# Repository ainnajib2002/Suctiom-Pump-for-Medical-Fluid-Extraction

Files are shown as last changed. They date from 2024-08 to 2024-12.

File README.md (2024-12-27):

## Suction-Pump-for-Medical-Fluid-Extraction








# Suction Pump for Medical Fluid Extraction

## Deskripsi Proyek
Suction Pump adalah alat medis untuk menghisap berbagai jenis cairan tubuh seperti darah, lendir, dan nanah selama prosedur medis. Proyek ini dirancang untuk menghasilkan suction pump berbasis mikrokontroler Arduino Mega dengan fitur IoT, keypad, dan LCD untuk pemantauan dan kontrol yang lebih baik.

---

## Fitur Utama
- **IoT Integration**: Pemantauan dan kontrol jarak jauh melalui cloud.
- **User Interface**: Keypad 4x4 dan LCD 20x4 untuk pengoperasian mudah.
- **Safety Design**: Bahan stainless steel untuk ketahanan dan kebersihan.

---

## Alat dan Bahan
| Komponen | Deskripsi |
|---|---|
| **Mikrokontroler**  | Arduino Mega |
| **Sensor** | MPX 5700 untuk tekanan |
| **Komponen Elektrik**| LCD 20x4, Keypad Matrix 4x4, Driver Motor L298N, Potentiometer |
| **Komponen Mekanikal**| Bahan stainless steel untuk casing dan komponen mekanis lainnya |

---

## Desain 3D
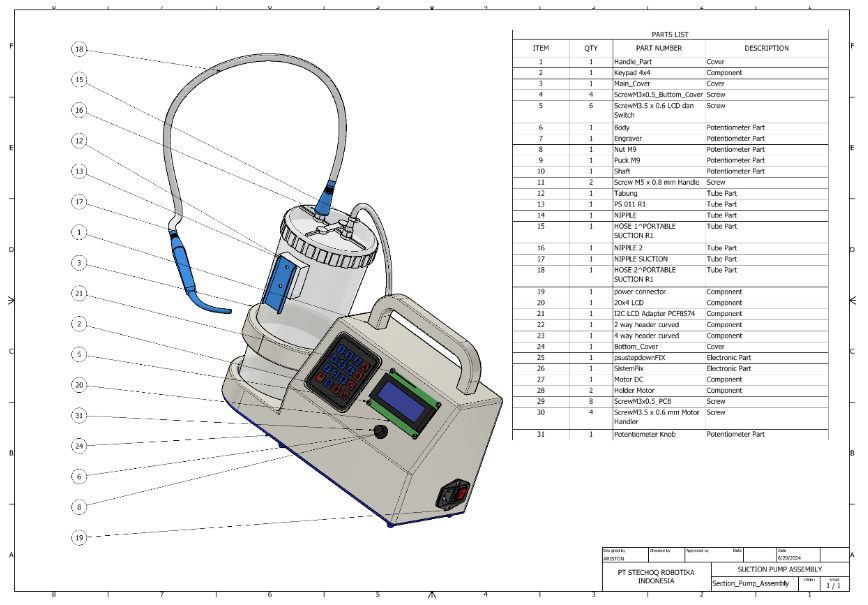
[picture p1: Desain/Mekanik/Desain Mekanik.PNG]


## Skema Rangkaian


---

## Panduan Instalasi dan Penggunaan
1. **Persiapan Hardware**: 
   - Rakit semua komponen sesuai skema.
   - Pastikan koneksi ke ESP32 dan sistem mekanik sudah sesuai.
2. **Instalasi Software**:
   - Gunakan Arduino IDE untuk mengunggah kode ke mikrokontroler.
3. **Konfigurasi IoT**:
   - Masukkan detail WiFi melalui keypad untuk koneksi cloud.
4. **Pengoperasian**:
   - Gunakan keypad untuk mengatur kecepatan dan parameter operasi.
   - Pantau informasi pada LCD 20x4.

---

## Sumber
- [Arduino IDE](https://www.arduino.cc/en/software)
- [Komponen ESP32](https://www.espressif.com/en/products/socs/esp32)

---

Jika desain ini sudah sesuai, saya dapat menambahkan detail lainnya. Silakan beri tahu!

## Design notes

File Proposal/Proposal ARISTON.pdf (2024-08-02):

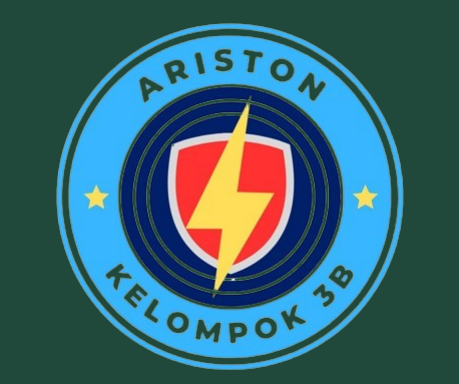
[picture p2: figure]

# ARISTON TEAM

## PT. STECHOQ ROBOTIKA INDONESIA

Jl. Bunga J5, Kentungan, Condongcatur, Depok,

### Sleman, D.I. Yogyakarta 55281

ASSOCIATED WITH :

# Project Proposal

# Suction Pump for Medical Fluid Extraction

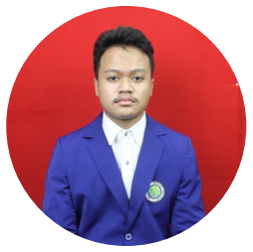
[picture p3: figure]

Sholich Ibnu Damar

3D Design
Universitas Negeri Malang

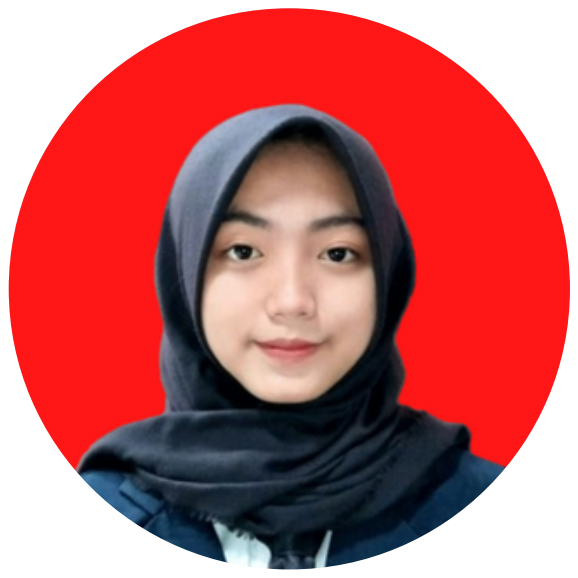
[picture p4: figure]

Tri Rejeki Andani

3D Design
Universitas Negeri Surabaya

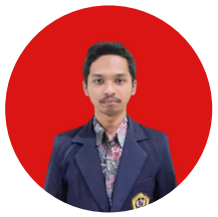
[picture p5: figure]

Sri Aji Eka Mahendra

Electronics Engineer
Universitas Merdeka Malang

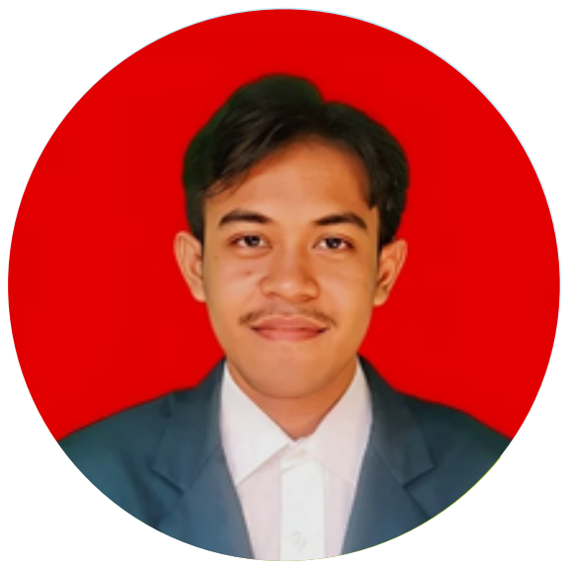
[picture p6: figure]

Ainun Najib Khasbunallah

Project Manager and Electronics Engineer Universitas Diponegoro Semarang

# OUR TEAM

### SUCTION PUMP FOR MEDICAL FLUID EXTRACTION

ARISTON | PAGE 1

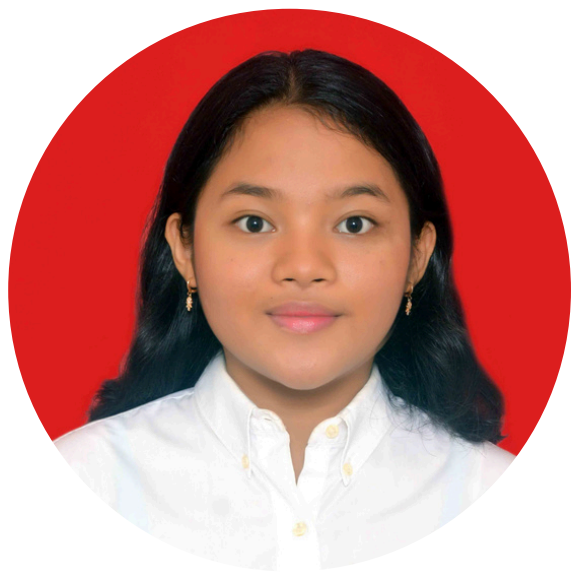
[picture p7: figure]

Aurelia Alika Putri Widiyanta

Administratif and Support Engineer Politeknik Negeri Semarang

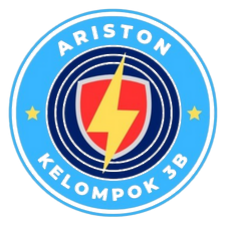
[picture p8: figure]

### ARISTON

Jl. Bunga J5, Kentungan, Condongcatur, Kab. Depok, Kab. Sleman, Daerah Istimewa Yogyakarta

### HALAMAN PENGESAHAN

### 1. Nama Proyek : Project Proposal Suction Pump for Medical Fluid Extraction 2. Bidang Riset : Hardware Engineering 3. Nama Tim : ARISTON 4. Anggota Tim : - Ainun Najib Khasbunallah - Aurelia Alika Putri Widiyanta - Sholich Ibnu Damar - Sri Aji Eka Mahendra - Tri Rejeki Andani

### Sleman, 24 Mei 2024

Menyetujui,

Koordinator Lapangan | Project Manager
(Nama) | Ainun Najib Khasbunallah

Mengetahui,

Direktur Utama PT. Stechoq | Person In charge

### Robotika Indonesia

Malik Khidir, S.Si | Febri Hari Natoro, S.Psi

# Daftar Isi

01

## BAB 1 – PENDAHULUAN

## Latar Belakang

## Rumusan Masalah Tujuan dan Sasaran

## Scope Of Work

## ANGGOTA TIM

## HALAMAN PENGESAHAN

## DAFTAR ISI

## BAB 2 – DETAIL PROYEK

## Deskripsi Produk

## Sistem Kerja Alat

## Spesifikasi Alat

## Skema Elektronik

## BAB 3 - METODE DAN TAHAPAN

## Timeline

## Work Breakdown Structure Rencana Anggaran Biaya

## BAB 4 – PENUTUP

## Penutup

## LAMPIRAN

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
Suction pump adalah perangkat medis yang dirancang khusus untuk menghisap cairan tubuh. Suction pump medis dapat digunakan dalam berbagai penerapan pada bidang medis, termasuk di ruang operasi, unit perawatan intensif, ruang gawat darurat, atau klinik medis. Dalam industri perawatan kesehatan, mesin suction pump telah menjadi bagian penting dalam proses penghisapan cairan tubuh pasien selama prosedur medis. Dalam produk ini penggunaannya dilengkapi dengan kontrol yang memungkinkan pengaturan tingkat hisap yang diperlukan sesuai dengan kebutuhan spesifik prosedur atau kondisi pasien untuk membantu meningkatkan efisiensi, keamanan, dan kualitas perawatan pasien.

Berdasarkan hal ini, kami dari peserta studi independen PT Stechoq Robotika Indonesia berusaha untuk memberikan kontribusi dalam menyelesaikan permasalahan yang terjadi dan meningkatkan efisiensi dalam industri perawatan kesehatan. Pada program studi independen MSIB batch VI, dirancang sebuah inovasi “Suction Pump for Medical Fluid Extraction” yang merupakan produk inovatif dalam industri perawatan kesehatan dengan mesin suction pump. Penggunaan inovasi ini diharapkan dapat mempermudah operator perawatan kesehatan dalam memantau kinerja mesin suction pump Dengan ini diharapkan produk inovasi Suction Pump for Medical Fluid Extraction memberikan solusi yang canggih dan efisien dalam pemantauan dan pemeliharaan mesin suction pump, yang dapat meningkatkan efisiensi, kebersihan, dan keamanan dalam industri perawatan kesehatan.

## LATAR BELAKANG

# BAB 1 PENDAHULUAN

Berdasarkan latar belakang tersebut, didapatkan rumusan masalah, yaitu :
Bagaimana merancang suction pump yang efisien untuk digunakan dalam berbagai prosedur medis?

1.

2.Bagaimana menghubungkan teknologi IoT dalam suction pump?

## RUMUSAN MASALAH

Tujuan dari produk ini yaitu :
Mengembangkan desain rancangan suction pump yang mampu bekerja untuk berbagai kebutuhan medis, termasuk pembedahan dan perawatan pasien dengan gangguan cairan.

1.

Menghubungkan suction pump dengan teknologi Internet of Things (IoT) untuk meningkatkan kinerja, pemantauan, dan manajemen perangkat medis secara real-time.

2.

## TUJUAN DAN SASARAN

Ruang lingkup dari pengerjaan ini adalah :
1.Pembuatan desain mekanik dan elektrik 2.Pembuatan program
3.Peragaan simulasi alat

## SCOPE OF WORK

Suction Pump for Medical Fluid Extraction adalah perangkat medis yang dirancang khusus untuk mengeluarkan cairan tubuh seperti darah, lendir, dan cairan lainnya dari tubuh pasien atau area operatif secara cepat dan efisien. Alat ini sangat penting dalam berbagai prosedur medis, termasuk pembedahan, perawatan pasien dengan gangguan cairan, dan situasi darurat medis. Suction pump ini menawarkan solusi andal untuk meningkatkan kualitas pelayanan kesehatan. Selain itu, suction pump ini dilengkapi dengan layanan IoT (Internet of Things) yang memungkinkan pemantauan kinerja alat secara real-time yang optimal dan mengurangi downtime.

## DESKRIPSI PRODUK

# BAB 2 DETAIL PROYEK

Sistem ini dimulai dengan pemeriksaan status alat. Jika status alat baik, kemudian menkoneksikan Wi_Fi untuk terhubung dengan API Cloud. Pengguna dapat memilih mode kontrol mesin suction pump via keypad atau via IoT dengan menu slider. Setelah memasukkan RPM motor yang diinginkan dan menekan tombol untuk memulai pengisian. Motor kemudian memompa cairan ke dalam tabung sesuai RPM yang ditentukan.
Hasil pengisian ditampilkan pada layar LCD dan dikirim ke cloud melalui API. Data hasil pengisian dikirim ke database dan dapat dipantau melalui platform cloud. Sistem memastikan pengisian cairan otomatis dengan pemantauan real-time melalui LCD dan cloud, serta penyimpanan data yang efisien. Proses diakhiri setelah semua langkah selesai.

## SISTEM KERJA ALAT

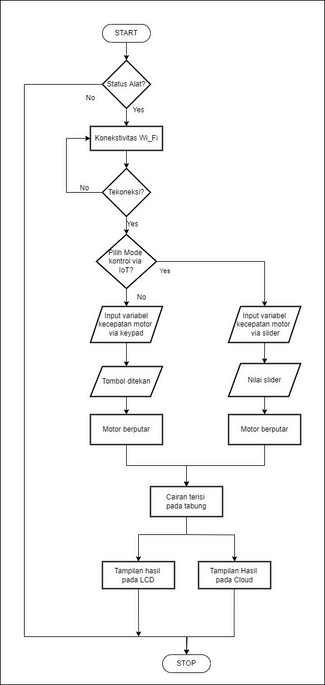
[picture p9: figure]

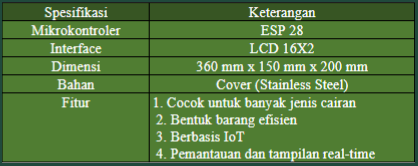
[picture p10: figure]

## LCD Keypad 16x2

## ESP32

## SPESIFIKASI ALAT

# BAB 2 DETAIL PROYEK

## Motor DC

## Tombol Keypad 4x4

## Potensiometer

## Power Supply 12V

## Stepdown 5V

## Push Button On/ Off

## SKEMA ELEKTRONIK

## TIMELINE

# BAB 3 METODE DAN TAHAPAN

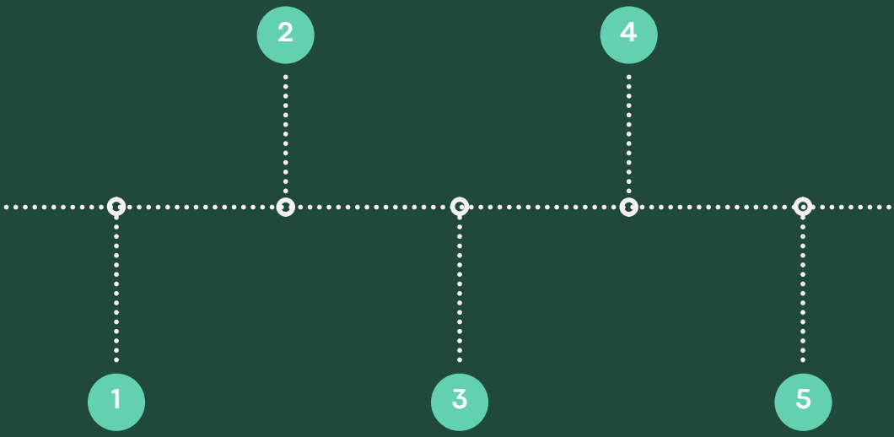
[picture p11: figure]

### Persiapan Pelaksanaan

### Pelaporan

### Perancangan

### Pengujian

Persiapan (1 Maret - 16 Maret)

Analisis tujuan dari project ARISTON, Pengumpulan data dan informasi produk, Analisis cara kerja dan komponen yang digunakan

Perancangan (17 Maret - 6 April)

Perancangan design 3d suction pump, Perancangan bahasa pemrograman C++, Perancangan design elektronika suction pump

Pelaksanaan (7 April - 30 April)

Membuat part-part design 3D suction pump, Membuat bahasa program arduino C++, pembuatan 3D animasi suction pump, Assembly design schematic rangkaian elektronika suction pump, Assembly design layout rangkaian elektronika suction pump, Assembly design 3D suction pump, Integrasi sistem suction pump dengan bahasa program

Pengujian (1 Mei - 25 Mei)

Pengujian fungsi dan kinerja sistem suction pump, Finishing dan evaluasi suction pump

Pelaporan (19 Mei- 10 Juni)

Pembuatan dan penyusunan laporan akhir, Presentasi project

## WORK BREAKDOWN STRUCTURE

# BAB 3 METODE DAN TAHAPAN

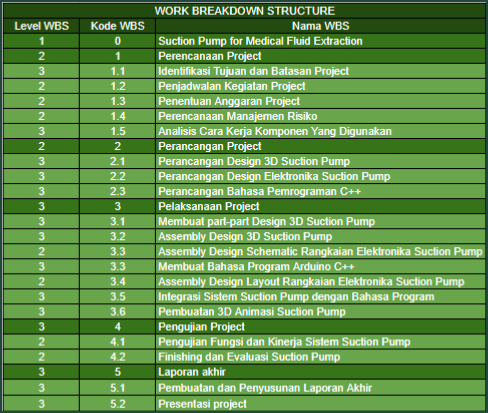
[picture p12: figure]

No | Nama | Harga
1. | Biaya elektrikal | Rp. 637.528
2. | Biaya mekanikal | Rp. 1.500.000
| Total | Rp. 2.137.528

## RENCANA ANGGARAN BIAYA

# BAB 3 METODE DAN TAHAPAN

## PENUTUP

# BAB 4 PENUTUP

Demikian proposal suction pump for medical fluid extraction dibuat dengan harapan alat ini tidak hanya meningkatkan efisiensi operasional dan kontrol yang presisi, tetapi juga memastikan keamanan dan kenyamanan bagi pengguna. Dengan kemampuan pemantauan real-time, pengendalian jarak jauh, analisis data yang mendalam, dan integrasi dengan sistem medis lainnya, perangkat ini siap mendukung para profesional medis dalam memberikan perawatan yang lebih baik dan responsif. Inovasi ini memperkuat komitmen terhadap kemajuan teknologi medis yang berpusat pada keselamatan dan kesejahteraan pasien, menjadikannya aset berharga dalam lingkungan medis modern.

# LAMPIRAN

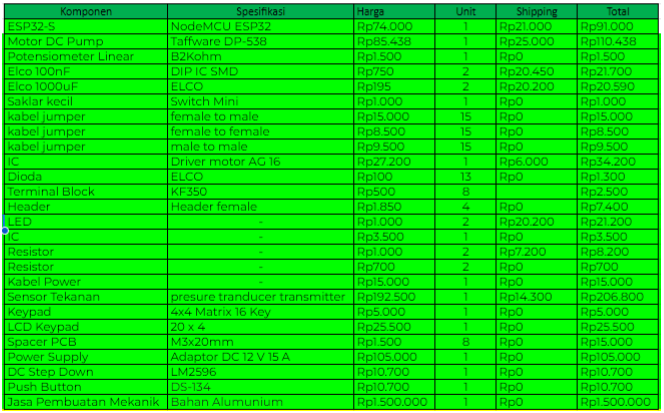
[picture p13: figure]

For inquiries,
contact ARISTON.

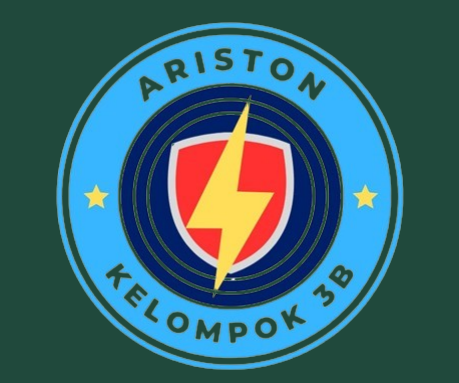
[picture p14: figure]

+62 857-1358-7044 (Ainun Najib) aristonhwstechoq@gmail.com

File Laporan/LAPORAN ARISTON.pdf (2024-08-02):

LAPORAN AKHIR
MAGANG DAN STUDI INDEPENDEN BERSERTIFIKAT SUCTION PUMP FOR MEDICAL FLUID EXTRACTION PT STECHOQ ROBOTIKA INDONESIA

Diajukan untuk Memenuhi Persyaratan Kelulusan Program MSIB MBKM

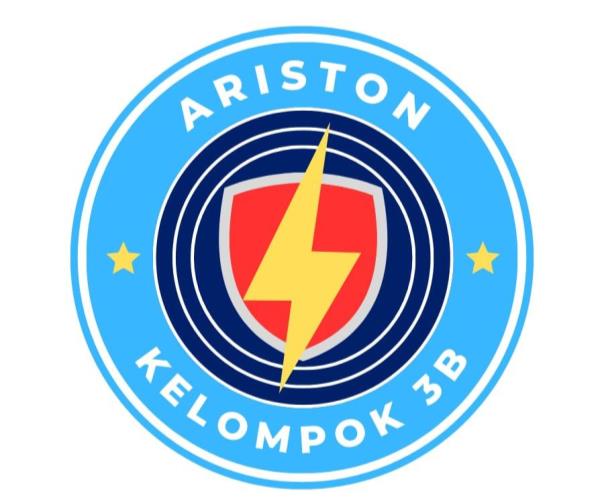
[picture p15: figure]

Ainun Najib Khasbunallah | Universitas Diponegoro
Aurelia Alika Putri Widiyanta | Politeknik Negeri Semarang
Sholich Ibnu Damar | Universitas Negeri Malang
Sri Aji Eka Mahendra | Universitas Merdeka Malang
Tri Rejeki Andani | Universitas Negeri Surabaya

MAGANG DAN STUDI INDEPENDEN BERSERTIFIKAT PT STECHOQ ROBOTIKA INDONESIA 2024

i

LEMBAR PENGESAHAN
SUCTION PUMP FOR MEDICAL FLUID EXTRACTION PT STECHOQ ROBOTIKA INDONESIA

oleh :

“ARISTON”

1. | Ainun Najib Khasbunallah | Universitas Diponegoro
2. | Aurelia Alika Putri Widiyanta | Politeknik Negeri Semarang
3. | Sholich Ibnu Damar | Universitas Negeri Malang
4. | Sri Aji Eka Mahendra | Universitas Merdeka Malang
5. | Tri Rejeki Andani | Universitas Negeri Surabaya

disetujui dan disahkan sebagai

Laporan Studi Independen Bersertifikat Kampus Merdeka

Sleman, 25 Juni 2024

Penanggung jawab Program MSIB | Project Manager
PT Stechoq Robotika Indonesia
Febri Hari Natoro, S.Psi | Ainun Najib Khasbunallah
Human Resources Supervisor

ii

ABSTRAK

Suction pump adalah alat medis yang digunakan untuk menghisap berbagai

jenis cairan tubuh. Alat ini dapat menghisap cairan yang terbentuk dari proses

sekresi tubuh seperti darah, air liur, nanah, lender, dan cairan lainnya yang perlu

dihilangkan atau dibersihkan karena tidak diperlukan oleh tubuh. Cairan tubuh yang

dihisap nantinya akan ditampung dalam sebuah wadah untuk ditindak lanjuti.

Suction pump biasanya terdiri dari motor, selang, botol penampung cairan,

manometer, dan katup-katup untuk hisap dan tekan. Sedangkan, untuk

menampilkan tekanan hisap, jenis cairan, dan hal lainnya yang bersifat monitoring

biasanya ditampilkan pada LCD. Pada perancangan alat ini, akan dilakukan

modifikasi, yaitu penggunaan mikrokontroler berupa Arduino Mega sebagai

pengendali, penambahan keypad, dan juga potensiometer yang digunakan sebagai

pengganti sensor tekan dalam rancangan desainn dan simulasi.

Kata kunci: alat medis, cairan tubuh, Arduino Mega

iii

ABSTRACT

The suction pump is a medical device used to extract various types of bodily

fluids. It can suction fluids formed from bodily secretion processes such as blood,

saliva, pus, lymph, and other fluids that need to be removed or cleaned as they are

not required by the body. The extracted bodily fluids are then collected in a

container for further action. Typically, a suction pump consists of a motor, tubing,

fluid collection bottle, manometer, and suction and pressure valves. Meanwhile, to

display suction pressure, fluid type, and other monitoring-related information, it is

usually shown on an LCD. In the design of this device, modifications will be made,

including the use of a microcontroller in the form of an Arduino Mega as the

controller, the addition of a keypad, and the integration of a potentiometer to

replace the pressure sensor in the design and simulation.

Keywords: medical device, bodily fluids, Arduino Mega

iv

KATA PENGANTAR

Puji syukur kami panjatkan kehadirat Tuhan Yang Maha Esa yang telah

memberikan rahmat serta karunia-Nya kepada kami sehingga kami berhasil

menyelesaikan laporan MSIB ini tepat pada waktunya dengan bidang “Hardware

Engineering in Industry 4.0 For Medical Devices”. Laporan MSIB ini

diharapkan dapat memberikan informasi kepada pembaca tentang pengerjaan

tugas akhir dengan judul “Suction Pump for Medical Fluid Extraction”. Pada

kesempatan ini kami menyampaikan banyak terima kasih kepada semua pihak

yang telah memberikan bimbingan dalam penyusunan laporan MSIB ini, terutama

kepada :

1. Orang tua dan segenap keluarga yang selalu memberikan dukungan dan

doa yang tidak ternilai harganya.

2. Bapak Malik Khidir selaku Direktur PT Stechoq Robotika Indonesia.
3. Mas Muhammad Minto Aji Shodiq selaku Person in Charge program

MSIB PT Stechoq Robotika Indonesia.

4. Seluruh jajaran mentor dari setiap divisi yang telah memberikan

dorongan, semangat, bimbingan, dan saran selama melakukan kegiatan

magang dan penulisan laporan magang MSIB ini.

5. Teman-teman serta rekan-rekan seperjuangan yang telah memberikan

dukungan selama ini dari awal Studi Independen sampai penyusunan

laporan ini.

6. Serta semua pihak yang tidak bisa penulis sebutkan satu persatu.

Penulis menyadari bahwa laporan ini masih jauh dari kata sempurna, oleh

karena itu segala kritik dan saran dari semua pihak yang bersifat membangun selalu

penulis harapkan demi kesempurnaan penulisan di masa yang akan datang. Akhir

kata, penulis ucapkan terima kasih kepada semua pihak yang telah berperan serta

dalam penyusunan.

Sleman, 25 Juni 2024

Ainun Najib Khasbunallah

v

DAFTAR ISI

LAPORAN AKHIR | a

vi

vii

DAFTAR GAMBAR

viii

ix

DAFTAR TABEL

1

BAB I

PENDAHULUAN

### 1.1 Latar Belakang

Pendidikan memiliki peran penting dalam memberikan pemahaman dan

keterampilan kepada individu melalui konsep-konsep teoritis yang umumnya

diajarkan dalam konteks pendidikan formal. Harapannya, setelah menyelesaikan

pendidikan, seseorang mampu beradaptasi dengan perubahan dan kemajuan dalam

dunia pendidikan dengan mendorong pengembangan pendekatan yang lebih

fleksibel dan adaptif terhadap kebutuhan mahasiswa serta dinamika zaman. Akan

tetapi, dalam pelaksanaannya terdapat ketimpangan antara teori-teori dan praktik

langsung dalam dunia kerja. Pada dunia kerja seseorang dituntut untuk mempunyai

keterampilan yang lebih dari sekedar pengetahuan akademis. Kemampuan untuk

berpikir kritis, beradaptasi, berinovasi, dan berkomunikasi efektif menjadi

kemampuan yang sangat penting. Pengenalan mahasiswa terhadap lingkungan kerja

bertujuan untuk memberi pemahaman yang lebih dalam tentang realita dan

dinamika yang ada di tempat kerja, sehingga mahasiswa dapat memperoleh

wawasan yang lebih luas tentang bagaimana proses dan dinamika kerja sebenarnya

berlangsung.

Kampus Merdeka, yang digagas oleh Kementerian Pendidikan,

Kebudayaan, Riset, dan Teknologi (Kemendikbud Ristek), menyelenggarakan

Program Magang dan Studi Independen Bersertifikat (MSIB) untuk memberikan

mahasiswa kesempatan yang lebih besar dalam mengembangkan keterampilan dan

pengetahuan praktis dalam lingkungan kerja yang nyata. Program ini dikelola oleh

Direktorat Jenderal Pendidikan Tinggi, Riset, dan Teknologi (Ditjen Dikti-Ristek)

Indonesia. Program yang ditawarkan memberikan tantangan dan peluang bagi

mahasiswa untuk mengembangkan inovasi, kreativitas, kapasitas, kepribadian,

serta kebutuhan mahasiswa. Melalui program ini, mahasiswa didorong untuk

mandiri dalam mengeksplorasi pengetahuan melalui pengalaman langsung di lapangan, menghadapi tantangan nyata, berinteraksi secara sosial, berkolaborasi,

manajemen diri, dan mencapai target yang ditetapkan.

Pada program magang dan studi independen bersertifikat mahasiswa dapat

memilih program dan mitra dari berbagai bidang seperti bidang teknik, industri

makanan, film, teknologi, dan sebagainya untuk menjadi tempat pembelajaran

selama 1 semester setiap periodenya. Salah satu mitra sejak dibukanya MSIB batch

1, PT Stechoq Robotika Indonesia telah menjadi mitra utama dari Program Magang

dan Studi Independen Bersertifikat dalam lingkup Kampus Merdeka. Perusahaan

PT Stechoq Robotika Indonesia bergerak pada bidang penelitian dan

pengembangan, dengan fokus pada inovasi produk dalam berbagai sektor, termasuk

kesehatan, peternakan, manufaktur, dan pendidikan..

PT Stechoq Robotika Indonesia menawarkan mahasiswa untuk

menjalankan program Studi Independen berupa pembekalan teknis terkait

Hardware Engineering. Yang meliputi: desain produk, pengembangan perangkat

lunak, pengembangan perangkat keras, komunikasi nirkabel, teknologi sensor.

Setiap bidang akan ditugaskan sesuai dengan pedoman standar yang telah

ditetapkan oleh perusahaan. Mahasiswa diberi kesempatan untuk mengembangkan

inovasi dalam proyek dengan tema tertentu yang disesuaikan dengan batasan yang

telah ditetapkan. Selama proses penelitian, mahasiswa akan dibimbing oleh mentor

ahli dalam bidangnya masing-masing. Setelah menyelesaikan program, mahasiswa

diwajibkan untuk menyusun laporan yang kemudian akan didiskusikan dengan

pembimbing lapangan dan dosen pembimbing magang sebagai bagian dari evaluasi

program.

### 1.2 Tujuan

Berdasarkan latar belakang yang telah disusun, didapatkan tujuan dari

penyusunan laporan adalah:

1. Memenuhi kewajiban sebagai mahasiswa.
2. Melaporkan masalah, proses dan hasil riset kepada perusahaan selaku mitra

dan fasilitator riset.

3

### 1.3 Manfaat

Berdasarkan latar belakang yang telah disusun, didapatkan manfaat dari

penyusunan laporan adalah:

1. Bagi perusahaan sebagai sarana untuk pengembangan produk inovasi

melalui riset yang dilakukan oleh mahasiswa magang sehingga perusahaan

mendapatkan masukan untuk menentukan kebijakan perusahaan di masa

yang akan datang khususnya di bidang teknologi dan informasi. Perusahaan

mendapat sudut pandang yang berbeda dalam menilai dan melihat keadaan

perusahaan. Sebagai bentuk keikutsertaan perusahaan dalam memajukan

pembangunan di bidang pendidikan dan peningkatan sumber daya manusia.

2. Bagi mahasiswa untuk menambah wawasan dan pengetahuan tentang dunia

kerja selama di lapangan. Mahasiswa akan merasakan secara langsung

perbedaan antara teori di dalam perkuliahan dengan yang ada di lapangan.

Serta dapat meningkatkan pengalaman mahasiswa dalam dunia kerja dan

mengembangkan soft skills maupun hard skills yang dimiliki mahasiswa

selama | mengikuti | program | magang | MSIB. | Mahasiswa | dapat

mengembangkan dan mengaplikasikan pengalaman di kerja lapangan untuk

dijadikan sebagai bahan pertimbangan tugas akhir/ skripsi.

BAB II

PROFIL MITRA

### 2.1 Pengenalan Mitra

Pada bab ini membahas mengenai pengenalan mitra yang merupakan aspek

penting dalam memperkenalkan mahasiswa kepada lingkungan kerja dan industri

terkait.

### 2.2.1 Deskripsi Mitra

PT Stechoq Robotika Indonesia (STECHOQ) merupakan perusahaan

research and development yang berfokus dalam mengembangkan inovasi produk

teknologi robotika dan Industrial IoT (Internet of Things) 4.0. Didirikan pada tahun

2015 oleh para milenial berprestasi yang berhasil meraih belasan prestasi di bidang

robotika dalam maupun luar negeri. Dengan 100% pemilik modal dalam negeri,

STECHOQ telah berhasil dan akan terus menggembangkan produk inovasi tepat

guna untuk kemajuan bangsa Indonesia, antara lain Ventilator ICU pertama buatan

anak bangsa, Electronic Nose, Digital Control System dan Mini Plant Production

System. Kantor pusat STECHOQ beralamatkan di Jalan Belimbing A17,

Perumahan Sidoarum Blok II, Godean, Kramat. Sidoarum, Sleman, Daerah

Istimewa Yogyakarta.

Gambar 2. 1 Logo STECHOQ

### 2.2.2 Visi dan Misi

A. Visi

Menjadi perusahaan riset dan manufaktur terkemuka yang berkomitmen

mendorong terwujudnya Indonesia maju dengan:

1. Mengembangkan teknologi dan menghasilkan inovasi produk dalam

negeri berkualitas global.

5

2. Meningkatkan kualitas SDM dan mengembangkan Startup
3. Membuat karya yang berguna untuk bangsa.
B. Misi
1. Melakukan kolaborasi riset dan pengembangan inovasi teknologi tepat

guna sesuai kebutuhan industri dan masyarakat.

2. Menjalankan proses produksi massal dari hasil riset yang telah

dilakukan dengan sistem produksi ramping.

3. Mengadakan pelatihan dan sertifikasi.
4. Membina IKM dengan program berkelanjutan.

### 2.2 Struktur Organisasi

Bagan struktur organisasi dari PT Stechoq Robotika Indonesia dapat

dilihat pada Gambar 2.2 Struktur Organisasi.

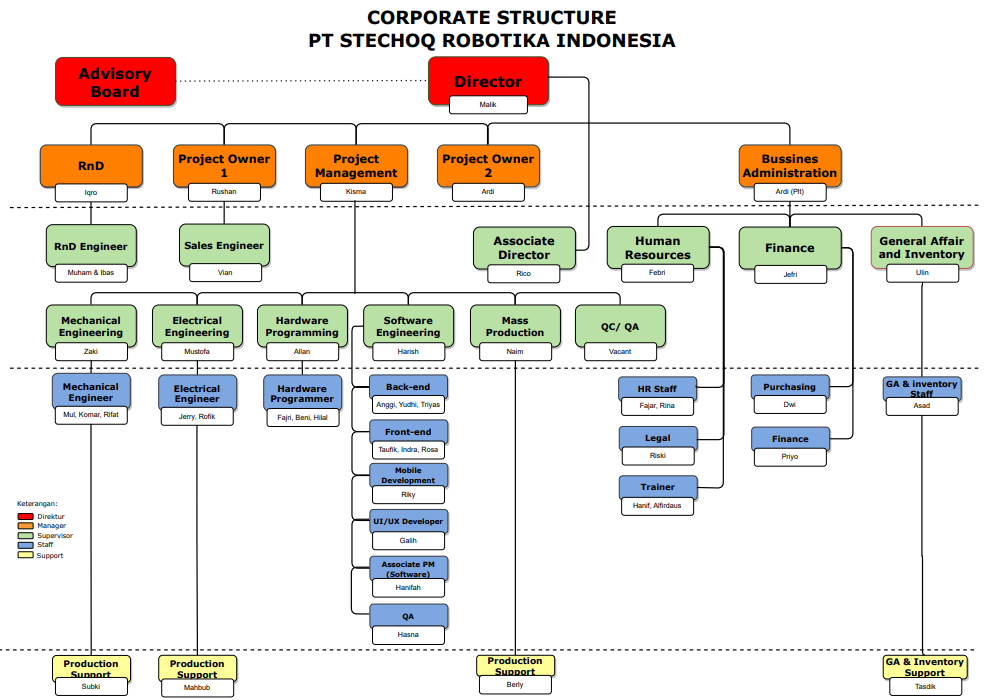
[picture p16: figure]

Gambar 2. 2 Struktur Organisasi

### 2.3 Sejarah dan Perkembangan

PT Stechoq Robotika Indonesia merupakan perusahaan R&D (Research and

Development) yang berfokus dalam mengembangkan inovasi produk teknologi

Robotika dan Industrial IoT 4.0. Kantor Pusat PT Stechoq beralamatkan di Jalan

Belimbing A17, Perumahan Sidoarum Blok II, Godean, Kramat. Sidoarum, Sleman,

DIY. Bapak Malik Khidir merupakan pendiri dari PT Stechoq Robotika Indonesia.

Bapak Malik Khidir merupakan alumni dari prodi Elektronika dan

Instrumentasi, Universitas Gadjah Mada. Sejak kuliah, beliau sering mengikuti

perlombaan robotik hingga ke luar negeri seperti di Amerika dan Kanada. Dari

kompetisi tersebut, beliau dan tim memenangkan beberapa penghargaan medali.

Melihat adanya peluang yang sangat tinggi pada bidang teknologi, beliau kemudian

mulai mendirikan PT Stechoq Robotika Indonesia.

PT Stechoq Robotika Indonesia didirikan pada 2015 oleh Bapak Malik

Khidir. Kantor dari perusahaan ini semula berada di Krapyak. Pada awalnya,

perusahaan ini bergerak pada teknologi dengan ranah bidang militer. Akan tetapi,

bidang militer hanya sebatas dijadikan riset. Kemudian pada tahun selanjutnya, PT

Stechoq Robotika Indonesia hanya melakukan beberapa riset saja tanpa ada

produksi massal.

Seiring berjalannya waktu, terjadi pandemi Covid-19. PT Stechoq Robotika

Indonesia mengalami kebangkitan karena mampu menciptakan Genose. Produksi

massal Genose memberikan keuntungan yang sangat besar bagi PT Stechoq

Robotika Indonesia. Selanjutnya, PT Stechoq Robotika Indonesia berhasil.

### 2.4 Lingkungan Kerja

Program Studi Independen pada judul Hardware Engineering in Industry

4.0 For Medical Devices dilaksanakan dengan sistem 100% daring selama 4

(empat) bulan, melalui platform Training Center PT Stechoq Robotika Indonesia.

### 2.5 Jadwal Kerja

Pada awal pelaksanaan program MSIB di PT Stechoq Robotika Indonesia,

diadakan pembekalan bagi peserta berupa gambaran materi-materi hingga hal teknis

yang berhubungan dengan proses pelatihan. Bentuk pembekalan yang dilakukan

berupa materi presentasi dari mentor, kerja kelompok, tugas individu yang terkait

dengan materi materi yang akan dipelajari.

Jadwal kegiatan pembelajaran Studi Independen di PT Stechoq Robotika

Indonesia dilakukan Forum Group Discussion (FGD) 2 kali dalam seminggu yang

7

dilaksanakan oleh mentor dengan mahasiswa. Kemudian, di tengah dan akhir

semester juga diadakan sebuah ujian untuk menguji pemahaman materi maupun

tugas yang dikerjakan mahasiswa.

BAB III

DASAR TEORI

Pada bab ini akan membahas tentang beberapa dasar teori atau referensi yang

menjadi dasar dalam penyusunan tugas akhir. Pembahasan ini dimaksudkan untuk

mendukung alat yang akan dibuat agar berjalan sesuai dengan yang diinginkan.

### 3.1 Suction Pump

Suction pump adalah perangkat medis yang digunakan untuk

menghilangkan dan membersihkan cairan yang tidak diperlukan saat proses operasi.

Proses yang dilakukan mesin ini dengan cara menghisap cairan berupa darah, air

liur, nanah, atau lendir dari tubuh pasien yang terbentuk dari proses sekresi tubuh

dalam kondisi tertentu. Suction pump memanfaatkan daya hisap dari motor pompa

untuk menghisap cairan tubuh pasien. Berikut merupakan gambar suction pump

ditunjukkan pada gambar 3.1.

Gambar 3. 1 Suction Pump

Alat medis ini terdiri dari motor sebagai penggerak untuk sistem hisap dan

tabung sebagai tempat media cairan yang dihisap. Terdiri dari dua buah selang,

masing-masing berfungsi sebagai selang hisap dan selang buang, selang hisap

dihubungkan langsung dengan pasien dan selang buang dihubungkan dengan sistem

hisap dari motor. Suction Pump merupakan alat medis yang masuk ke kategori alat

medis life support untuk membantu petugas medis dalam menjalankan pekerjaanya.

9

Dari beberapa cairan yang dapat dibersihkan mesin sction pump ini secara umum

digunakan untuk membersihkan jalan nafas yang mengalami hambatan karena

sekret/cairan/ lendir sehingga jalan nafas menjadi bersih dan kebutuhan gas dapat

terpenuhi, dan juga digunakan untuk menghapus darah dari daerah yang

dioperasikan.

### 3.2 Mikrokontroller ESP 32

ESP32 adalah sebuah mikrokontroler open source yang dapat mengontrol

perangkat elektronik lainnya. Mikrokontroler ini dapat terintegrasi dengan sensor

dan aktuator serta dapat dimodifikasi berdasarkan perangkat yang ingin dibuat.

ESP32 menggunakan prosesor dual-core Xtensa LX6. Komponen penting yang

termasuk di dalamnya yaitu pin digital dan analog, koneksi Wi-Fi dan Bluetooth,

serta koneksi USB. Umumnya papan ESP32 diaplikasikan ke dalam sistem kendali

di bidang Internet of Things (IoT), instrumentasi, dan kontrol otomatis..

Gambar 3. 2 ESP 32

Pada gambar 3.2 ditunjukan mikrokontroller ESP32 yang memiliki

spesifikasi seperti pada tabel 3.1 berikut:

Tabel 3. 1 Spesifikasi Mikrokontroller ESP32

Spesifikasi | Detail
Mikrokontroller | ESP 32
CPU | Tensilica Xtensa LX6 32 bit Dual- Core
SRAM | 520 kb

Spesifikasi | Detail
Tegangan Kerja | 2.2V – 3.6 V
Analog Pin I/O | 18 (12bit)
Digital Pin I/O | 2 (8bit)
Pin I/O Digital PWM | 8
I2C | 2
SPI | 4
Arus Kerja | 80 mA
Program | Ya (C, C++, Python, Lua)
Open Source | Ya
Memori Flash | 2MB (max 64 MB)
Dimensi | 48.26 x 27.94 mm

### 3.3 LCD (Liquid Crystal Display) 20x4

LCD adalah sebuah teknologi tampilan visual yang menggunakan cairan

kristal untuk menghasilkan gambar. Layar LCD terdiri dari lapisan-lapisan yang

berbeda yang untuk mengatur cahaya dan menghasilkan gambar. Prosesnya

melibatkan polarisasi cahaya melalui lapisan kristal cair yang bisa dikontrol secara

elektrik. Ketika tegangan diterapkan pada lapisan-lapisan tersebut, orientasi kristal

cair berubah, mengubah cara cahaya melewati layar dan menghasilkan gambar.

Penggunaan LCD biasanya diterapkan pada perangkat elektronik seperti televisi,

monitor komputer, kalkulator.

Gambar 3. 3 LCD

11

Pada gambar 3.3 ditunjukan mikrokontroller LCD (Liquid Crystal Display)

yang memiliki spesifikasi seperti pada tabel 2.2 berikut:

Tabel 3.3 Spesifikasi LCD (Liquid Crystal Display)

Spesifikasi | Detail
Display Kontroller | HD44780
Tegangan Kerja | 5 VDC
Tampilan | 2 baris, 16 karakter
Dimensi Layar | 64,5 x 16 mm
Dimensi Modul | 80 36 x 12 mm

### 3.4 Matrix Keypad 4x4

Keypad adalah bagian penting dari suatu perangkat elektronika yang

membutuhkan interaksi manusia. Keypad berfungsi sebagai interface antara

perangkat elektronika atau dikenal dengan istilah HMI (Human Machine Interface).

Matrix Keypad ini memiliki konstruksi atau susunan yang sederhana dan hemat

dalam penggunaan port mikrokontroler. Konfigurasi keypad dengan susunan

bentuk matrix ini bertujuan untuk penghematan port mikrokontroler karena jumlah

tombol yang dibutuhkan banyak pada suatu sistem mikrokontroler.

Gambar 3. 4 Matrix Keypad 4x4

Konstruksi matrix keypad 4x4 cukup sederhana, yaitu terdiri dari 4 baris dan

4 kolom dengan bentuk saklar push button yang diletakkan di setiap persilangan

kolom dan 4 kolom. Delapan line yang terdiri dari 4 baris dan 4 kolom tersebut

dihubungkan dengan port mikrokontroler 8 bit. Sisi baris dari Matrix Keypad

ditandai dengan nama Row1, Row2, Row3 dan Row4 kemudian sisi kolom ditandai dengan nama Col1, Col2, Col3 dan Col4. Sisi input atau output dari Matrix Keypad

4×4 ini tidak mengikat, dapat dikonfigurasikan kolom sebagi input dan baris

sebagai output atau sebaliknya.

### 3.5 Potensiometer

Potensiometer adalah sebuah jenis resistor yang nilai tahanannya atau

hambatannya (resistansi) dapat diubah atau diatur (adjustable). Potensiometer

memiliki 3 terminal, 2 terminal terhubung ke kedua ujung elemen resistif, dan

terminal ketiga terhubung ke kontak geser yang disebut wiper. Posisi wiper

menentukan tegangan keluaran dari potensiometer. Potensiometer pada dasarnya

berfungsi sebagai pembagi tegangan variabel. Unsur resistif dapat dilihat sebagai

dua resistor seri, dimana posisi wiper menentukan rasio resistensi dari resistor

pertama ke resistor kedua. Potensiometer juga dikenal sebagai potmeter atau pot.

Bentuk paling umum dari potmeter adalah potmeter putar. Jenis pot sering

digunakan dalam kontrol volume suara audio dan berbagai aplikasi lainnya. Unsur

resistif pada potensiometer biasanya terbuat dari bahan seperti karbon, keramik

logam, gulungan kawat (wirewound), plastik konduktif, atau film logam.

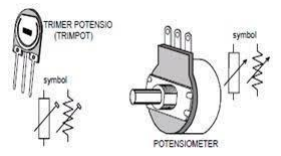
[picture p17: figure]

Gambar 3. 5 Potensiometer

### 3.6 Power Supply

Power Supply adalah sebuah piranti elektronika yang berguna sebagai

sumber daya supaya piranti lain dapat bekerja. Catu daya memiliki rangkaian yang

mengubah arus listrik AC menjadi DC. DC Power Supply atau Catu Daya ini juga

sering dikenal dengan nama “Adaptor”. Catu daya 11 memilki 4 bagian utama agar

dapat menghasilkan arus DC yang stabil. Keempat bagian tersebut di antaranya :

a. Transformator

13

b. Penyearah (Rectifier)
c. Penyaring (Filter)
d. Regulator yang berfungsi sebagai penstabil tegangan.

Prinsip kerja catu daya (power supply) dapat dipelajari sesuai

bagianbagiannya masing-masing seperti skema rangkaian sederhana berikut ini

Gambar 3. 6 Skema Rangkaian Power Supply

a. Transformator

Transformator merupakan komponen utama dalam membuat

rangkaian catu daya yang berfungsi untuk mengubah tegangan listrik, yakni

menaikkan dan menurunkan tegangan. Berdasarkan tegangan yang

dikeluarkan dibagi menjadi 2 yaitu: Trafo Step Up dan Trafo Step Down.

Pada pembuatan catu daya, trafo yang digunakan adalah trafo step down

yang berfungsi menurunkan tegangan 220 VAC menjadi tegangan yang

lebih kecil (5V, 9V, 12V) atau sesuai kebutuhan. Transformator berkerja

berdasarkan prinsip induksi elektromagnetik yang terdiri lilitan primer dan

lilitan sekunder. Lilitan primer merupakan input dari tarfo dan lilitan

sekunder sebagai outputnya. Setelah diturunkan oleh trafo Step-down,

tegangan yang dihasilkan masih berbentuk arus bolak-balik (AC) yang

kemudian akan di masukkan ke dalam rangkaian penyearah (Rectifier).

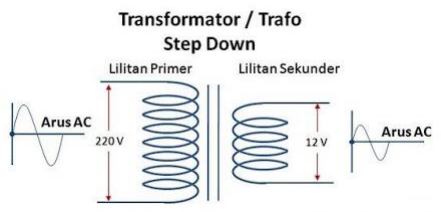
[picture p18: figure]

Gambar 3. 7 Transformator

b. Rectifier (Penyearah Gelombang)

Peranan rectifier dalam rangkaian catu daya adalah untuk mengubah

tegangan listrik AC menjadi tegangan listrik DC. Rectifier biasanya terdiri

dari dioda-dioda. Pada rangkaian penyearah terdapat 2 jenis yaitu “Half

Wave Rectifier” yang terdiri dari 1 komponen dioda dan “Full Wave

Rectifier” yang terdiri 2 atau 4 komponen diode. Bentuk gelombang pada

tahap penyearah seperti pada gambar 3.8.

Gambar 3. 8 Gelombang Keluaran Penyearah
c. Filter (Penyaring)

Filter merupakan bagian yang terdiri dari kapasitor yang berfungsi

untuk meratakan sinyal arus DC yang berasal dari rectifier. Akibat dari

pemasangan kapasitor sebagai filter, tegangan DC akan menjadi lebih halus

dan bersih, Sehingga gelombang yang keluar merupakan gelombang output

VD. Bentuk gelombang pada tahap penyaring seperti pada gambar 3.9.

15

Gambar 3. 9 Gelombang Keluaran Kapasitor

d. Voltage Regulator

Voltage regulator adalah bagian yang terdiri dari diode Zener, transistor, IC

atau kombinasi dari ketiga komponen tersebut. Komponen ini berfungsi

sebagai penstabil dan pengatur tegangan DC yang berasal dari rangkaian

penyaring, agar tidak terpengaruh oleh tegangan beban. Terdapat beberapa

seri IC yaitu komponen seri 78XX sebagai regulator tegangan tetap positif

dan seri 79XX yang merupakan regulator untuk tegangan tetap negatif.

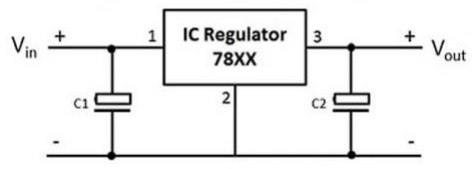
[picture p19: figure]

Gambar 3. 10 Rangkaian Dasar IC Voltage Regulator

BAB IV

PENJELASAN RISET

### 4.1 Produk Riset

Suction Pump for Medical Fluid Extraction merupakan sebuah perangkat

medis yang dirancang khusus untuk menghisap cairan tubuh, seperti darah, lendir,

atau cairan lainnya, selama prosedur medis atau pembersihan luka. Produk ini

melibatkan pengembangan desain perangkat keras yang memadai untuk

memastikan tingkat hisap yang optimal, kemudahan penggunaan, dan keamanan

operasi. Riset ini melibatkan pemilihan komponen, perancangan sirkuit, dan

integrasi teknologi sensor dan kontrol yang diperlukan. Dalam penelitian ini

suction pump dirancang dengan kemampuan untuk mengatur tingkat daya hisap

sesuai dengan kebutuhan spesifik prosedur medis atau pasien tertentu. Hal ini

memungkinkan untuk pengaturan alat yang akurat sesuai kebutuhan ataupun

prosedur medis.

Saat penggunaan suction pump proses kontrol dan monitoring pada produk

ini dapat dipahami dengan mudah. Operator dapat mengontrol dan memantau

tingkat hisap, dan fungsi-fungsi lainnya dengan mudah karena dihubungkan

dengan keypad matrix, potensiometer serta LCD 20x4 sebagai monitoing

parameter alat. Produk ini diharapkan dapat bekerja secara kontinu tanpa overheat

atau kegagalan, serta menggunakan sumber daya yang efisien.

Gambar 4. 1 Suction Pump for Medical Fluid Extraction

17

### 4.2 Latar Belakang

Suction pump adalah perangkat medis yang dirancang khusus untuk

menghisap cairan tubuh. Suction pump medis dapat digunakan dalam berbagai

penerapan pada bidang medis, termasuk di ruang operasi, unit perawatan intensif,

ruang gawat darurat, atau klinik medis. Dalam industri perawatan kesehatan, mesin

suction pump telah menjadi bagian penting dalam proses penghisapan cairan tubuh

pasien selama prosedur medis. Dalam produk ini penggunaannya dilengkapi dengan

kontrol yang memungkinkan pengaturan tingkat hisap yang diperlukan sesuai

dengan kebutuhan spesifik prosedur atau kondisi pasien untuk membantu

meningkatkan efisiensi, keamanan, dan kualitas perawatan pasien.

Berdasarkan hal ini, kami dari peserta studi independen PT Stechoq

Robotika Indonesia berusaha untuk memberikan kontribusi dalam menyelesaikan

permasalahan yang terjadi dan meningkatkan efisiensi dalam industri perawatan

kesehatan. Pada program studi independen MSIB batch VI, dirancang sebuah

inovasi “Suction Pump for Medical Fluid Extraction” yang merupakan produk

inovatif dalam industri perawatan kesehatan dengan mesin suction pump.

Penggunaan inovasi ini diharapkan dapat mempermudah operator perawatan

kesehatan dalam memantau kinerja mesin suction pump Dengan ini diharapkan

produk inovasi Suction Pump for Medical Fluid Extraction memberikan solusi yang

canggih dan efisien dalam pemantauan dan pemeliharaan mesin suction pump, yang

dapat meningkatkan efisiensi, kebersihan, dan keamanan dalam industri perawatan

kesehatan.

### 4.3 Identifikasi Masalah

Berdasarkan latar belakang yang sudah dijelaskan, maka dapat disimpulkan

beberapa permasalahan yang terjadi, yaitu:

1. Bagaimana merancang suction pump yang efisien untuk digunakan dalam

berbagai prosedur medis?

2. Bagaimana menghubungkan teknologi IoT dalam suction pump?

### 4.4 Batasan Proyek

Dalam perancangan penelitian ini, diberikan batasan-batasan sebagai

berikut:

1. Penelitian ini hanya dilakukan sampai perancangan desain dan simulasi.
2. Penelitian dilakukan dengan bantuan data-data dan referensi komponen

dari PT Stechoq Robotika Indonesia.

### 4.5 Tujuan Proyek

Tujuan dalam perancangan penelitian ini adalah sebagai berikut:

1. Mengembangkan desain rancangan suction pump yang mampu bekerja

untuk berbagai kebutuhan medis, termasuk pembedahan dan perawatan

pasien dengan gangguan cairan.

2. Menghubungkan suction pump dengan teknologi Internet of Things (IoT)

untuk meningkatkan kinerja, pemantauan, dan manajemen perangkat medis

secara real-time.

### 4.6 Sasaran

Sasaran pembuatan desain dan simulasi produk “Suction Pump for Medical

Fluid Extraction” adalah untuk menghasilkan produk inovatif yang memenuhi

kebutuhan industri perawatan kesehatan dengan mesin suction pump. Desain dan

simulasi produk ini bertujuan untuk menciptakan sebuah perangkat yang dapat

meningkatkan efisiensi dan keamanan dalam proses penghisapan cairan tubuh

pasien selama prosedur medis. Selain itu, produk ini juga diharapkan dapat

mempermudah operator perawatan kesehatan dalam memantau kinerja mesin

suction pump.

19

BAB V

PELAKSANAAN TUGAS AKHIR

### 5.1 Struktur Tim

Gambar 5. 1 Struktur Tim Riset

Pada Gambar 5.1 dapat dilihat struktur tim riset yang telah dibentuk, kelima

anggota untuk mengerjakan tugas selama program Studi Independen dimulai sesuai

bidang yang telah ditentukan. Satu mahasiswa sebagai Project Manager dan empat

lainnya menjadi anggota yang mengurusi masing-masing bidang, yaitu 1 anggota

divisi administrative dan support engineering, 1 anggota divisi electrical

engineering, dan 2 anggota divisi 3d design.

Setiap anggota memiliki tugas yang telah ditentukan oleh PT Stechoq

Robotika Indonesia dan berdasarkan hasil dari penilaian terhadap pembelakan yang

dilakukan oleh masing-masing mentor divisi. Pada kegiatan riset, sistem kerja yang

diterapkan adalah tim kami dibimbing oleh mentor lapangan, mentor ahli, dan

Person in Charge (PIC) yang bertugas sebagai pembimbing serta pihak yang

menyetujui segala pengajuan riset.

### 5.2 Metodologi Pengerjaan

Tabel 4. 1 Work Breakdown Structure

WORK BREAKDOWN STRUCTURE

Level WBS | Kode WBS | Nama WBS
1 | 0 | Suction Pump for Medical Fluid Extraction
2 | 1 | Perencanaan Project
3 | 1.1 | Identifikasi Tujuan dan Batasan Project
2 | 1.2 | Penjadwalan Kegiatan Project

2 | 1.3 | Penentuan Anggaran Project
2 | 1.4 | Perencanaan Manajemen Risiko
3 | 1.5 | Analisis Cara Kerja Komponen Yang Digunakan
2 | 2 | Perancangan Project
3 | 2.1 | Perancangan Design 3D Suction Pump
3 | 2.2 | Perancangan Design Elektronika Suction Pump
3 | 2.3 | Perancangan Bahasa Pemrograman C++
3 | 3 | Pelaksanaan Project
3 | 3.1 | Membuat part-part Design 3D Suction Pump
3 | 3.2 | Assembly Design 3D Suction Pump
2 | 3.3 | Assembly Design Schematic Rangkaian Elektronika Suction Pump
3 | 3.3 | Membuat Bahasa Program Arduino C++
2 | 3.4 | Assembly Design Layout Rangkaian Elektronika Suction Pump
3 | 3.5 | Integrasi Sistem Suction Pump dengan Bahasa Program
3 | 3.6 | Pembuatan 3D Animasi Suction Pump
3 | 4 | Pengujian Project
2 | 4.1 | Pengujian Fungsi dan Kinerja Sistem Suction Pump
2 | 4.2 | Finishing dan Evaluasi Suction Pump
3 | 5 | Laporan akhir
3 | 5.1 | Pembuatan dan Penyusunan Laporan Akhir
3 | 5.2 | Presentasi project

Untuk mempermudah perencanaan pengerjaan, tim kami menyusun WBS

(Work Breakdown Structure). Prosesnya dibagi menjadi 5, yaitu :

1. Perencanaan Project

Bagian ini mencakup semua kegiatan terkait dengan perencanaan

awal proyek, termasuk identifikasi tujuan, batasan proyek, penjadwalan

kegiatan, penentuan anggaran, perencanaan manajemen risiko, dan analisis

cara kerja komponen.

21

2. Perancangan Project

Bagian ini fokus pada desain produk, termasuk perancangan model

3D dari Suction Pump, perancangan komponen elektronika, dan

perancangan bahasa pemrograman yang digunakan untuk kontrol Suction

Pump.

3. Pelaksanaan Project

Bagian ini melibatkan implementasi fisik dari rencana desain yang

telah dibuat sebelumnya. Ini termasuk pembuatan bagian-bagian fisik dari

Suction Pump, perakitan semua komponen, integrasi sistem, serta

pembuatan dokumentasi visual seperti animasi atau gambaran visual

lainnya.

4. Pengujian Project

Bagian ini mencakup semua aktivitas pengujian yang dilakukan

untuk memastikan bahwa Suction Pump berfungsi sesuai dengan spesifikasi

yang ditetapkan. Ini termasuk pengujian fungsi dan kinerja sistem serta

evaluasi keseluruhan dari hasil pengujian.

5. Laporan akhir

Bagian ini meliputi penulisan dan penyusunan laporan akhir yang

mencakup semua aspek proyek, termasuk tujuan, proses perancangan, hasil

pengujian, serta rekomendasi atau temuan penting lainnya. Laporan ini

biasanya menjadi dokumen penting untuk pembelajaran dan referensi di

masa depan.

### 5.3 Timeline Pengerjaan

Gambar 5. 2 Timeline Pengerjaan

1. Persiapan (1 Maret - 16 Maret)

Analisis tujuan dari project ARISTON, Pengumpulan data dan

informasi produk, Analisis cara kerja dan komponen yang digunakan.

2. Perancangan (17 Maret - 6 April)

Perancangan design 3d suction pump, Perancangan bahasa

pemrograman C++, Perancangan design elektronika suction pump.

3. Pelaksanaan (7 April - 30 April)

Membuat part-part design 3D suction pump, Membuat bahasa

program arduino C++, pembuatan 3D animasi suction pump, Assembly

design schematic rangkaian elektronika suction pump, Assembly design

layout rangkaian elektronika suction pump, Assembly design 3D suction

pump, Integrasi sistem suction pump dengan bahasa program.

4. Pengujian (1 Mei - 25 Mei)

Pengujian fungsi dan kinerja sistem suction pump, Finishing dan

evaluasi suction pump.

5. Pelaporan (19 Mei- 10 Juni)

Pembuatan dan penyusunan laporan akhir, Presentasi project.

### 5.4 Proses Pengerjaan Proyek

1. Mekanik
1. Persiapan

Pada bagian ini, kegiatan yang dilakukan adalah memahami terlebih

dahulu seperti apa alat ini dibuat nantinya. Pencarian data dan literatur yang

berhubungan dengan suction pump dan juga desain 3D yang cocok untuk

digunakan. Pada bagaian ini juga dilakukan pengidentifikasian alat dan

komponen apa saja yang diperlukan agar desain yang ada lebih praktis dan

mudah dipahami.

2. Perancangan

Tahap perancangan ini berisi penggambaran untuk kesimpulan dan

pembuatan sketsa gambar 3D yang akan dibuat. Tahap ini pengerjaan telah

mencapai angka 30%.

23

3. Pelaksanaan

Bagian pelaksanaan adalah bagian yang berisikan pengerjaan

pembuatan desain mekanik keseluruhan. Bagian ini seluruh desain dibuat

sesuai dengan pembagian section yang telah ditentukan dengan ukuran yang

sudah dipastikan dengan benar.

4. Pengujian

Bagian ini semua part dari tiap section disatukan dan dilihat apakah

ada kesalahan dalam ukuran komponen mekanik maupun elektrik. Jika

terdapat kesalahan, dilakukan juga revisi untuk perbaikannya sehingga

dapat dirangkai sesuai target.

5. Pelaporan

Bagian pelaporan adalah pembuatan laporan pembuatan dan

spesifikasi desain seperti ukuran dan rencana bahan agar orang bisa lebih

mudah memahami model dan bentuk desain yang akan dibuat. Pada bagian

ini juga dilakukan presentasi terhadap alat yang sudah dibuat.

2. Elektrik
1. Persiapan

Pada bagian ini, kegiatan yang dilakukan adalah memahami terlebih

dahulu bagaimana komponen elektrik dari sistem suction pump akan

dirancang dan diintegrasikan. Proses ini melibatkan pencarian data dan

literatur yang berhubungan dengan komponen elektronik yang digunakan

dalam suction pump, serta desain rangkaian elektronik yang cocok untuk

digunakan. Selain itu, pada tahap ini juga dilakukan identifikasi alat dan

komponen apa saja yang diperlukan agar desain elektrik yang ada lebih

praktis dan mudah dipahami.

2. Perancangan

Pada tahap perancanga, elektrik sudah mendapatkan gambarang

komponen yang akan digunakan dan mulai memilih komponen apa saja

yang sesuai dengan alat yang akan dibuat. Tidak hanya itu, pada bagian ini

elektrikjuga sudah dalam tahap pengerjaan 30%.

3. Pelaksanaan

Bagian pelaksanaan adalah bagian yang berisikan pengerjaan

pembuatan rangkaian elektrik keseluruhan. Bagian ini seluruh elektrik

dibuat sesuai dengan pembagian rangkaian dan kebutuhan elektrik yang

telah ditentukan.

4. Pengujian

Pada bagian pengujian elektrik dilakukan finishing dan juga

pembuatan simulasi rangkaian agar dapat diketahui apakah rangkaian dapat

bekerja sesuai dengan flowchart yang dibuat dengan komponen yang sudah

dipilih. Jika masih terjadi kesalahan, dilakukan perbaikan berupa revisi

hingga rangkaian elektrik bekerja sempurna.

5. Pelaporan

Bagian pelaporan adalah pembuatan laporan pembuatan dan

spesifikasi alat dan bahan serta dokumentasi pengerjaan agar dapat

dipahami oleh orang lain. Pada bagian ini juga dilakukan presentasi terhadap

alat yang sudah dibuat.

3. Program
1. Persiapan

Pada bagian ini, kegiatan yang dilakukan adalah memahami terlebih

dahulu bagaimana komponen elektrik dari sistem suction pump akan

dirancang dan diintegrasikan, termasuk bagaimana pemrograman

mikrokontroler dilakukan untuk mengoperasikan komponen-komponen

tersebut. Proses ini melibatkan pencarian data dan literatur yang

berhubungan dengan komponen elektronik yang digunakan dalam suction

pump, serta desain rangkaian elektronik yang cocok untuk digunakan.

Selain itu, pada tahap ini juga dilakukan identifikasi alat dan komponen apa

saja yang diperlukan agar dapat diketahui program seperti apa yang cocok

untuk spesifikasi alat yang dibuat

2. Perancangan

Tahap perancangan untuk program digunakan untuk pembuatan alur

sistem kerja alat agar program yang dibuat dapat berjalan sesuai yang

25

diingikan. Pada bagian ini, perancangan program sudah dilakukan dengan

komponen elektrik yang sudah pasti.

3. Pelaksanaan

Bagian pelaksanaan pembuatan program berisikan pembuatan

program untuk mikrokontroller agar dapat diintegrasikan dengan masing-

masing komponen yang digunakan. Pada bagian ini dilakukan pula

pengambilan range input agar alat dapat bekerja dengan maksimal. Dan

dikarenakan alat ini juga bersifat IoT, maka dilakukan pula integrasi dengan

sistem IoT yang dilakukan dengan web WokWi agar mempermudah

simulasi.

4. Pengujian

Bagian pengujian berisikan assembly antara program dengan

perangkat hardware elektrik yang dibuat agar dapat bekerja sebagaimana

mestinya. Pada bagian ini, dilakukan simulasi dan pengiriman data dan

pengoreksian apakah sistem dapat bekerja dengan benar. Jika masih ada

yang salah maka dilakukan revisi sesuai dengan kesalahan yang terjadi.

5. Pelaporan

Bagian pelaporan adalah pembuatan laporan pembuatan dan

penjelasan tiap program agar program dapat dipahami oleh orang lain. Pada

bagian ini juga dilakukan presentasi terhadap alat yang sudah dibuat.

### 5.5 Sistem Kerja

### 5.5.1 Sistem Kerja Elektrik

Gambar 5. 3 Skema Elektrik

Sistem kerja elektrik suction pump berbasis Arduino dimulai dengan suplai

daya dari power supply 12 VDC. Tegangan ini kemudian di-stepdown

menggunakan regulator untuk menghasilkan output 5 VDC yang dibutuhkan oleh

mikrokontroler ESP32, sementara tegangan 12 VDC langsung digunakan sebagai

input untuk driver motor L298N. Sistem dihidupkan dan dimatikan menggunakan

push button yang terhubung ke ESP32. Input kontrol disediakan oleh

potensiometer, yang mengatur kecepatan motor DC, dan keypad 4x4, yang

memungkinkan pengguna memasukkan berbagai perintah dan pengaturan. ESP32

mengolah input ini dan mengirimkan sinyal kontrol ke driver motor L298N, yang

kemudian mengatur motor DC valve untuk mengendalikan operasi suction pump.

Seluruh sistem dimonitoring melalui LCD keypad 16x2 yang menampilkan

informasi penting seperti status sistem dan kecepatan motor, memastikan pengguna

dapat memantau dan menyesuaikan operasi sesuai kebutuhan.

### 5.5.2 Flowchart Sistem Suction Pump

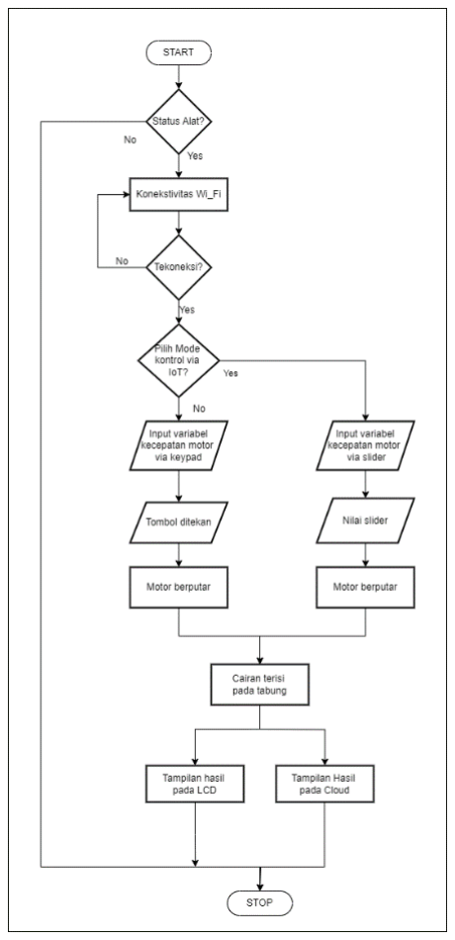
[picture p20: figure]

Gambar 5. 4 Flowchart Sistem Suction Pump

27

Proses dimulai dengan sistem memeriksa status alat. Jika alat tidak siap,

proses kembali ke awal. Namun, jika alat dalam kondisi siap, pengguna akan

diminta untuk memasukkan kecepatan motor yang diinginkan melalui antarmuka

alat. Setelah kecepatan motor diinput, pengguna menekan tombol untuk memulai

pengoperasian motor dengan kecepatan yang telah ditentukan. Motor kemudian

mulai bergerak sesuai dengan kecepatan yang diinputkan. Ketika motor mencapai

kecepatan yang diinginkan, hasilnya ditampilkan pada layar LCD yang terpasang

pada alat, memberi informasi visual kepada pengguna. Selanjutnya, data mengenai

kecepatan motor dikirim ke cloud melalui API yang tersedia, memungkinkan data

untuk diakses dari lokasi yang terhubung ke internet.

Selain itu, jika konektivitas Wi-Fi diperlukan, sistem akan memeriksa

konektivitas Wi-Fi. Pengguna akan diminta untuk memasukkan SSID dan password

Wi-Fi untuk menghubungkan alat dengan jaringan internet. Sistem kemudian

memeriksa apakah perangkat berhasil terhubung ke jaringan Wi-Fi. Jika tidak

terkoneksi, pengguna harus memasukkan kembali SSID dan password. Jika

perangkat terkoneksi dengan jaringan Wi-Fi, data kecepatan motor akan dikirim ke

database melalui koneksi internet dan hasilnya juga ditampilkan pada platform

Cloud yang terhubung.

Proses berakhir dengan menampilkan hasil kecepatan motor pada platform

Cloud serta mengakhiri pengoperasian alat. Dengan demikian, flowchart ini

menggambarkan alur pengoperasian suction pump yang mengukur dan

menampilkan kecepatan motor, serta mengirim data kecepatan motor ke cloud,

dengan tambahan langkah untuk memastikan konektivitas Wi-Fi jika diperlukan.

### 5.6 Inovasi

1. Cocok untuk banyak jenis cairan

Inovasi ini memungkinkan suction pump untuk menangani berbagai

jenis cairan tubuh seperti darah, lendir, cairan lambung, dan cairan serosa.

Dengan material yang aman dan steril, serta desain yang memungkinkan

pengoperasian tanpa kontaminasi silang, pompa ini bisa digunakan dalam

berbagai prosedur medis seperti pembedahan, endoskopi, dan perawatan

luka. Fleksibilitas ini mengurangi kebutuhan untuk memiliki berbagai alat

untuk setiap jenis cairan, meningkatkan efisiensi operasional rumah sakit

atau klinik.

2. Bentuk efisien

Desain yang efisien mencakup ukuran yang lebih kompak dan

portabel, memudahkan pemindahan dan penggunaan di berbagai lokasi

dalam fasilitas medis. Bentuk yang ergonomis memungkinkan tenaga medis

untuk mengoperasikan alat ini dengan mudah, bahkan dalam situasi darurat.

Desain komponen yang meminimalkan gesekan dan kebisingan saat operasi

juga membuat pompa ini lebih nyaman digunakan, mengurangi gangguan

pada pasien dan lingkungan kerja.

3. Berbasis IoT

Integrasi teknologi IoT dalam suction pump memungkinkan

pemantauan dan kontrol jarak jauh. Dengan sensor yang terhubung, pompa

dapat memonitor kondisi operasional seperti tekanan, aliran, dan volume

cairan yang dikeluarkan secara real-time. Data ini dapat diakses melalui

aplikasi atau platform berbasis web, memungkinkan tenaga medis untuk

segera merespon jika terjadi masalah. Fitur IoT juga mendukung

pemeliharaan prediktif (predictive maintenance), sehingga kerusakan dapat

diantisipasi dan diperbaiki sebelum terjadi, mengurangi waktu henti alat dan

biaya perbaikan. Selain itu, integrasi ini juga memungkinkan pencatatan

otomatis data medis terkait dengan penggunaan pompa, yang dapat

diintegrasikan ke dalam sistem rekam medis elektronik (Electronic Health

Records/EHR).

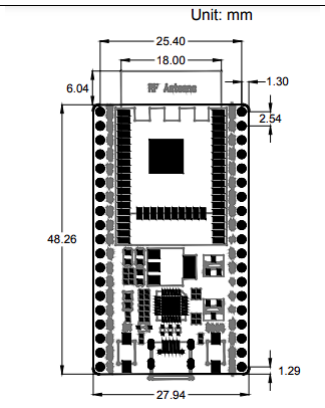
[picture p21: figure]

29

### 5.7 Komponen

### 5.7.1 Electrical

Berikut adalah komponen yang digunakan untuk elektrik dan spesifikasinya :

ESP 32

- Catu daya : 5VDC
- | Mendukung | konektifitas | WiFi,

Bluetooth Classic, dan Bluetooth Low

| Energy
- Dilengkapi konverter USB-to-UART
| internal CP2102
- Menggunakan SoC berbasis ESP32-

D0WD (dual-core Xtensa 32-bit LX6

MCU) @240 MHz

- Mendukung protokol jaringan WiFi

802.11 b/g/n @ 2.4 GHz ~ 2.5 GHz

- terintegrasi dengan SPI Flash 4 MB
- Memenuhi sertifikasi FCC-US, CE-

EU, IC-CA, TELEC-JP, SRRC and

| KCC-KR
- Antarmuka : UART / I2C / I2 S / SPI /
| ADC
- Jumlah pin I/O : 38 Pin
- Memiliki dimensi 48.26 x 27.94 mm

Keypad 4x4

Specifications

- Maximum Rating: 24 VDC, 30 mA
- Interface: 8-pin access to 4x4 matrix
- Operating temperature: 32 to 122 °F

(0 to 50°C)

- Dimensions:

Keypad, 2.7 x 3.0 in (6.9 x 7.6 cm)

Cable: 0.78 x 3.5 in (2.0 x 8.8 cm)

- Jumlah tombol: 8 (0-9,A,B,C,D,*,#)

L298N

- Input Voltage: 3.2V~40Vdc
- Driver: L298N Dual H Bridge DC Motor

Driver

- Power Supply: DC 5 V - 35 V
- Peak current: 2 Amp
- Operating current range: 0 ~ 36mA
- Control signal input voltage range :

Low: -0.3V ≤ Vin ≤ 1.5V.

High: 2.3V ≤ Vin ≤ Vss.

- Enable signal input voltage range :

Low: -0.3 ≤ Vin ≤ 1.5V (control signal is

invalid).

High: 2.3V ≤ Vin ≤ Vss (control signal

active).

- Maximum power consumption: 20W

(when the temperature T = 75 ℃).

- Storage temperature: -25 ℃ ~ +130 ℃.

31

- On-board +5V regulated Output supply

(supply to controller board i.e. Arduino).

- Size: 4.3cm x 4.3cm x 2.6cm

LCD 20x4

- Compatible with Arduino Board or other

controller board with I2C bus.

- Display Type: Black on yellow green

backlight.

- I2C Address:0x38-0x3F (0x3F default)
- Supply voltage: 5V
- Interface: I2C to 4bits LCD data and

control lines.

- Contrast Adjustment : built-in

Potentiometer.

- Backlight Control: Firmware or jumper

wire.

- Board Size: 98x60 mm

Potensiometer

- Series : P232 & P233 Series
- Sub-Category: Resistor Trimmers,

Potentiometer

- Maximum Operating Temperature:

+ 85 C

- Minimum Operating Temperature:
- 10 C
- Type : Rotary Panel Potentiometer
- Voltage Rating : 200 VDC
- Life | : 2000000 Cycle

- Diameter : 23 mm • Resistance 10 kOhms • Shaft Diameter 6.35 mm • Element Type Conductive Plastic • Shaft Length 22 mm • Shaft Type Smooth / Slotted • Thread Size M9 x 0.75 • Number of Detents Without Detent • Bushing Material Metal • Bushing Thread M9 x 0.75

Spacer PCB ukuran M3 x 20mm mur dan baut 3mm tinggi 20mm ( 2cm )

Sensor Tekanan MPX 5700

Series MPX5700AP

Pressure Type : Absolute Pressure

Operating Pressure 101.53 PSI (700 kPa)

Output Type Analog Voltage

Output 0.2 V ~ 4.7 V

Accuracy 2.5%

Voltage - Supply 4.75 V ~ 5.25 V

Port Size Male - 0.19" (4.93mm) Tube

Port Style Barbed

Features Temperature Compensated

Termination Style PCB

Maximum Pressure 406.11 PSI (2800 kPa)

Operating Temperature -40C ~ 125C

33

### 5.7.2 Mekanikal

Komponen mekanikal dibuat dengan menggunakan bahan stainless steal.

Hal ini dilaku dengan beberapa pertimbangan. Alasannya adalah karena stainless

steel adalah bahan yang sering dipilih untuk desain suction pump karena sejumlah

alasan bagus. Pertama, mari kita lihat kekuatannya. Stainless steel sangat kuat dan

bisa menahan tekanan tinggi, yang sangat penting untuk pompa yang sering

mengalami tekanan besar. Ini berarti komponen-komponen pompa tidak akan

mudah rusak atau aus, sehingga pompa bisa bertahan lebih lama.

Ketahanan terhadap korosi adalah salah satu keunggulan utama stainless

steel. Bahan ini sangat tahan terhadap karat dan korosi, bahkan ketika terpapar air

atau bahan kimia. Jadi, jika Anda menggunakan pompa ini untuk memompa cairan

yang mungkin bersifat asam atau korosif, stainless steel adalah pilihan yang tepat.

Jenis stainless steel seperti 304 atau 316 memiliki lapisan pelindung alami yang

membantu mencegah karat.

Selain itu, stainless steel sangat higienis dan tidak reaktif. Ini berarti bahan

ini mudah dibersihkan dan disterilkan, yang sangat penting jika pompa digunakan

di industri makanan atau medis. Anda tidak perlu khawatir tentang kontaminasi

karena stainless steel tidak bereaksi dengan banyak bahan kimia.

Ketahanan terhadap suhu juga menjadi kelebihan lain. Stainless steel bisa

menahan suhu tinggi tanpa kehilangan kekuatannya, jadi jika pompa akan

digunakan dalam kondisi panas atau dingin, bahan ini tetap bekerja dengan baik.

Misalnya, dalam industri makanan atau farmasi, di mana sterilisasi sering

melibatkan suhu tinggi, stainless steel tetap stabil dan tidak berubah bentuk.

Dari sisi desain dan pembuatan, stainless steel bisa dibentuk dengan

berbagai cara, seperti pengelasan dan pemotongan, memberikan fleksibilitas dalam

pembuatan komponen pompa. Ini berarti pompa bisa didesain dengan bentuk dan

ukuran yang diinginkan tanpa banyak kendala.

Meski biaya awal stainless steel mungkin lebih tinggi dibandingkan dengan

bahan lain seperti plastik, tetapi dalam jangka panjang, bahan ini lebih ekonomis.

Karena sangat tahan lama dan memerlukan perawatan yang minimal, biaya

perbaikan dan penggantian komponen jadi jauh lebih rendah. Ini berarti Anda bisa

menghemat uang dalam jangka panjang meskipun investasi awalnya lebih besar.

Untuk bagian-bagian spesifik seperti body (casing) dan valve (katup),

stainless steel sangat ideal. Casing dari stainless steel akan melindungi komponen

internal dari kerusakan mekanis dan korosi, sementara valve yang terbuat dari

stainless steel akan memastikan kinerja yang konsisten dan tahan lama tanpa

kebocoran.

### 5.8 Desain

### 5.8.1 Electrical

1. Rangkaian Power Supply 12V

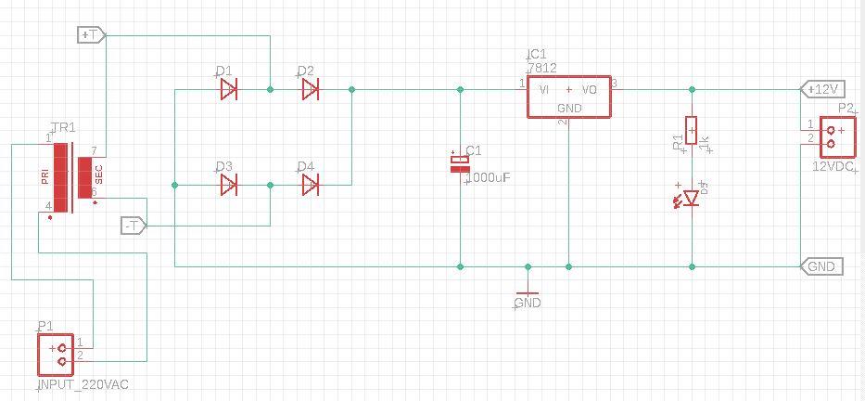
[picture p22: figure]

Gambar 5. 5 Schematic Rangkaian Power Supply 12V

Rangkaian power supply 12V adalah sebuah rangkaian yang

mengubah tegangan AC 220V dari sumber listrik menjadi tegangan DC 12V

yang stabil dan dapat digunakan untuk berbagai perangkat elektronik.

Proses ini dimulai dengan transformator yang menurunkan tegangan AC

220V menjadi 12V AC. Tegangan AC 12V ini kemudian disearahkan

menjadi tegangan DC yang masih berfluktuasi menggunakan bridge

rectifier. Tegangan DC berfluktuasi tersebut dihaluskan oleh kapasitor filter,

mengurangi ripple dan menghasilkan tegangan yang lebih stabil. Tegangan

stabil ini kemudian masuk ke voltage regulator (seperti IC 7812) yang

memastikan tegangan output tetap konstan pada 12V, meskipun ada

perubahan kecil pada tegangan input atau beban. Fuse ditempatkan untuk

melindungi rangkaian dari arus berlebih, memastikan keamanan operasional

dan mencegah kerusakan pada komponen lainnya. Dengan rangkaian ini,

35

perangkat elektronik dapat menerima suplai tegangan yang stabil dan aman,

sehingga kinerjanya lebih andal dan tahan lama.

2. Rangkaian Stepdown 5V

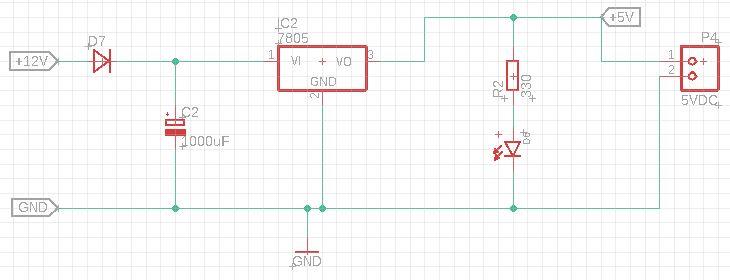
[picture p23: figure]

Gambar 5. 6 Schematic Rangkaian Stepdown 5V

Rangkaian stepdown 5V menggunakan voltage regulator 7805 untuk

menurunkan tegangan input yang lebih tinggi (misalnya 12V) menjadi 5V

yang stabil dan konstan. Proses ini dimulai dengan memasukkan tegangan

12V DC ke kapasitor input untuk mengurangi noise dan riak, sehingga

tegangan yang masuk ke regulator lebih stabil. Voltage regulator 7805

kemudian menurunkan tegangan 12V ini menjadi 5V pada pin outputnya.

Tegangan output ini kemudian melewati kapasitor output untuk lebih

menstabilkan tegangan 5V, memastikan bahwa perangkat yang

menggunakan tegangan ini tidak terganggu oleh fluktuasi atau noise. Karena

proses regulasi ini menghasilkan panas. Dengan menggunakan rangkaian

ini, berbagai perangkat elektronik yang membutuhkan tegangan 5V dapat

beroperasi dengan tegangan yang stabil dan andal.

3. Rangkaian Driver Motor DC L298N

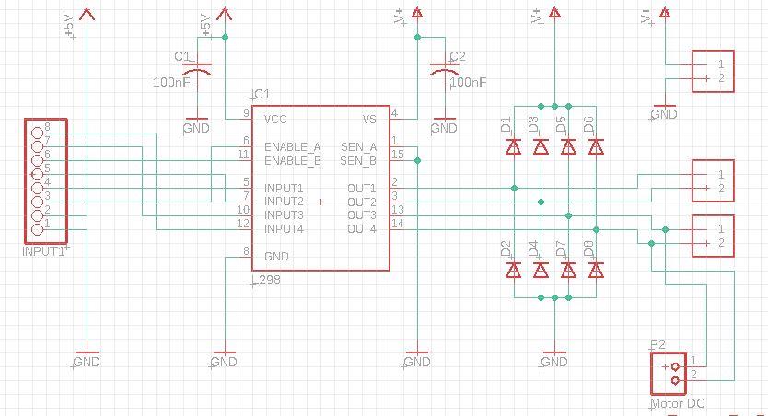
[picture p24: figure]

Gambar 5. 7 Schematic Rangkaian Driver Motor DC L298N

Rangkaian driver motor DC L298N menggunakan IC L298N untuk

mengendalikan dua motor DC secara independen atau satu motor stepper.

Sinyal kontrol dari mikrokontroler seperti Arduino atau ESP32 diterima

oleh pin input (IN1, IN2, IN3, IN4) pada IC, yang menentukan arah putaran

motor melalui konfigurasi H-Bridge internal. Kecepatan motor diatur

menggunakan sinyal PWM yang diterapkan pada pin enable (ENA, ENB),

dengan duty cycle PWM yang mengontrol kecepatan putaran. Tegangan

sumber daya untuk motor dan logika IC disuplai melalui pin power (Vcc,

GND). Tegangan yang diatur oleh IC kemudian dialirkan ke motor melalui

pin output (OUT1, OUT2, OUT3, OUT4). Dengan cara ini, arah dan

kecepatan putaran motor dapat dikendalikan secara tepat, memungkinkan

motor untuk bergerak sesuai dengan kebutuhan aplikasi.

37

4. Rangkaian ESP32

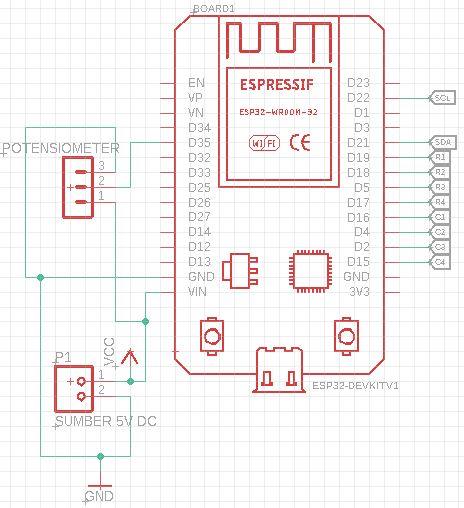
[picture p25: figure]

Gambar 5. 8 Schematic Rangkaian ESP32

Rangkaian ESP32 dirancang untuk mendukung berbagai aplikasi

IoT dengan mengandalkan kemampuan Wi-Fi dan Bluetooth dari chip

ESP32. Rangkaian ESP32 ini mendukung penggunaan keypad 4x4 untuk

input digital, LCD untuk tampilan, dan potensiometer untuk input analog.

Tegangan input 5V diatur oleh regulator tegangan menjadi 3.3V yang

dibutuhkan oleh ESP32, sementara kapasitor dan resistor menstabilkan

tegangan dan sinyal untuk operasi yang andal.

Gambar 5. 9 Schematic Rangkaian Connector Header

Keypad 4x4 terhubung ke beberapa pin GPIO pada ESP32,

memungkinkan pengguna untuk memberikan input digital melalui

penekanan tombol. LCD terhubung ke GPIO lainnya, memungkinkan

ESP32 untuk menampilkan informasi seperti data sensor atau status sistem.

Potensiometer terhubung ke pin ADC, memungkinkan ESP32 untuk

membaca nilai analog dan menggunakannya untuk mengatur parameter

tertentu dalam aplikasi. Dengan rangkaian ini, ESP32 dapat digunakan dalam berbagai proyek IoT yang memerlukan input dan output interaktif,

seperti sistem otomatisasi rumah, perangkat wearable yang cerdas, dan

banyak lagi.

5. Layout PCB


Gambar 5. 10 Layout PCB ESP32 dan Driver Motor L298N

Printed Circuit Board (PCB) adalah papan yang digunakan untuk

memasang dan menghubungkan berbagai komponen elektronik secara fisik

dan listrik. PCB terbuat dari bahan dasar yang isolatif, seperti fiberglass,

dengan lapisan konduktif tipis dari tembaga yang digunakan untuk membuat

jalur sirkuit. Layout diatas penempatan untuk ESP32 dan Driver Motor

L298N dengan PCB panjang 100 mm dan lebar 70 mm.


Gambar 5. 11 Layout PCB PSU 12V dan Stepdown 5V


39

Layout diatas penempatan untuk rangkaian PSU 12V dan Stepdown %v

dengan PCB panjang 70 mm dan lebar 50 mm.

### 5.8.2 Mekanikal

SPESIFIKASI MEKANIK

1. Assembly

Gambar 5. 12 Urutan Part pada Suction Pump Assembly


2. Cover
a. Cover Utama

Gambar 5. 13 Cover Utama Drawing

- Tampak Depan

Gambar 5. 14 Tampak Depan Cover Utama Drawing


41

- Tampak Bawah

Gambar 5. 15 Tampak Bawah Cover Utama Drawing

- Tampak Kanan

Gambar 5. 16 Tampak Kanan Cover Utama Drawing


3. Cover Penutup

Gambar 5. 17 Cover Penutup Drawing

4. Handle

Gambar 5. 18 Handle Drawing

43

5. Bottle
a. Tabung

Gambar 5. 19 Tabung Drawing


b. Nipple 2

Gambar 5. 20 Nipple 2 Drawing

c. Nipple Suction

Gambar 5. 21 Nipple Suction Drawing


45

d. Nipple

Gambar 5. 22 Nipple Drawing

e. PS 011 R1-1

Gambar 5. 23 PS011 R1-1 Drawing


6. Component
a. LCD 20x4 I2C

Gambar 5. 24 LCD 20 x 4 I2C Drawing

b. Keypad

Gambar 5. 25 Keypad Drawing

47

c. Potentiometer

Gambar 5. 26 Potentiometer Drawing

Link :

https://www.tme.com/Document/b026e638ce7c6fa81905a8d61b735da4/RV24.pdf

d. Potentiometer Knob

Gambar 5. 27 Potetiometer Knob Drawing


e. Switch

Gambar 5. 28 Switch Drawing

f. Baut
a. Baut M3.5 x 5 mm, Pitch 0.6 mm LCD dan Switch

Link : McMaster-Carr (https://www.mcmaster.com/products/screws/system-of-measurement~metric/thread-size~m3-5/length~5-mm/rounded-head-style~pan/material~18-8-stainless-steel/)

Gambar 5. 29 Baut M3.5 x 5 mm, Pitch 0.6 mm Drawing

49

b. Baut M5 x 10 mm, Pitch 0.8 mm Handle

Link : McMaster-Carr (https://www.mcmaster.com/products/screws/system-of-measurement~metric/thread-size~m5/length~10-mm/material~stainless-steel-2/drive-style~phillips/material~316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)


Gambar 5. 30 Baut M5 x 10 mm, Pitch 0.8 mm Handle Drawing

c. Baut M3 x 15 mm, Pitch 0.5 mm Penutup

Link : McMaster-Carr (https://www.mcmaster.com/products/screws/material~316-stainless-steel/specifications-met~iso-4762/)


Gambar 5. 31 Baut M3 x 15 mm, Pitch 0.5 mm Penutup Drawing


d. Baut M3 x 10 mm, Pitch 0.6 mm Motor Holder

Link : McMaster-Carr (https://www.mcmaster.com/products/screws/material~316-stainless-steel/specifications-met~iso-4762/)

Gambar 5. 32 Baut M3 x 10 mm, Pitch 0.6 mm Motor Holder

e. Baut M3 x 10 mm, Pitch 0.5 mm PCB

Link : McMaster-Carr (https://www.mcmaster.com/products/screws/material~316-stainless-steel/specifications-met~iso-4762/)

Gambar 5. 33 Baut M3 x 10 mm, Pitch 0.5 mm PCB

51

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

### 5.9 RAB Produk

Tabel 5. 1 RAB Produk
No | Nama | Harga
1. | Biaya Elektrikal | Rp. 637.528
2. | Biaya Mekanikal | Rp. 1.500.000
Total | | Rp. 2.137.528

### 5.10 Rancangan Tindak Lanjut

Rancangan yang dapat dikembangkan adalah pengembangan beberapa

komponen untuk menunjang fungsi dan keamanan alat. Beberapa komponen

tersebut adalah :

1. Pemberian tambahan sensor keamanan untuk pendeteksi kebocoran yang

berbentuk alarm dan pemberitahuan melalui media IoT.

2. Penambahan fitur pembersihan otomatis yang dapat mengurangi kontak

manusia terhadap cairan yang disedot agar berkurangnya resiko penularan

penyakit tertentu.

Dua hal diatas dapat digunakan pelaksanaan tindak lanjut untuk update dan

penambahan fitur pada suction pump.

### 5.11 Mentoring

Pada proses mengerjakan proyek, terdapat sesi mentoring atau laporan

progress kepada mentor mengenai perkembangan proyek dan pemantauan proses

pengerjaan agar mentor bisa memastikan proyek yang dikerjakan berjalan dengan

baik. Beberapa kegiatan mentoring yang dilakukan adalah sebagai berikut:

1. Weekly Report

Pada weekly report kegiatan yang dilakukan adalah melakukan

pelaporan mingguan bersama mentor korlap atau koordinator lapangan, dan

PIC. Hal yang dipresentasikan yaitu tentang proses yang dilakukan selama

seminggu, permasalahan yang ditemukan Ketika mengerjakan progres, dan

kegiatan selanjutnya yang akan dilakukan di satu pekan kedepan, Tujuan weekly report untuk menjaga progress dan memantau proses yang dilakukan

selama seminggu

2. Konsultasi Mentor Ahli

Pada mentoring ini hal yang lakukan adalah pelaporan dan

konsultasi kepada mentor ahli setiap divisi, terdapat 3 mentor ahli, dari

Software, Hardware, dan Mechanic. Kegiatan yang dilakukan adalah

melakukan konsultasi terkait kendala yang dialami selama proses

pengerjaan dan meminta bantuan kepada mentor ahli untuk solusi yang bisa

diambil.

53

BAB VI

PENUTUP

### 6.1 Kesimpulan

Secara umum dari alat yang telah kami buat mampu bekerja sesuai

perencanaan dan konsep awal serta sesuai dengan task yang telah diinginkan dari

desain awal beserta masukan dari mentor lapangan dan mentor ahli. Program

pengkondisi sinyal mampu menghasilkan pembacaan volume cairan medis dengan

baik pada ruangan yang diukur.

Sistem keseluruhan, baik elektrikal, pemrograman, maupun mekanikal yang

dipakai pada alat, mampu membaca volume cairan medis dengan baik di dalam

ruangan tertutup dan menampilkannya di LCD. Alat ini dapat mengatur nilai

ambang batas atas dan ambang batas bawah untuk mengatur kapan pompa hisap

diaktifkan sesuai keinginan. Selain itu, pompa hisap dapat menyalakan output

dengan baik, dan sistem dapat mengirim data kerja alat ke database serta

menampilkannya di situs web pemantauan. Dengan demikian, task tambahan dari

mentor ahli dapat diselesaikan dengan baik.

### 6.2 Kesan Mahasiswa

Mengikuti program studi independen di PT Stechoq Robotika Indonesia

adalah pengalaman yang sangat berharga bagi kami. Selama kegiatan ini, kami

mempelajari banyak hal, mulai dari rekayasa perangkat keras hingga keterampilan

komunikasi dan kerjasama dengan mahasiswa lain yang memiliki minat berbeda-

beda. Kami belajar untuk bekerja dengan baik dan harmonis dalam tim.

Kami berterima kasih kepada Kemendikbud Ristek yang telah memfasilitasi

program ini, sehingga mahasiswa dapat berkolaborasi dengan PT Stechoq Robotika

Indonesia dalam program Studi Independen Bersertifikat Merdeka Belajar Kampus

Merdeka. Kami juga mengucapkan terima kasih kepada semua anggota kelompok

Ariston yang telah bekerja sama menyelesaikan tugas, menyusun proyek, dan

membuat laporan. Tidak lupa, kami berterima kasih kepada para mentor yang telah

memberikan arahan dan masukan untuk proyek kami.

### 6.3 Saran

### 1. Saran Pelaksanaan Studi Independen

Pelaksanaan program Studi Independen Batch 6 MSIB di PT Stechoq

Robotika Indonesia telah berjalan sesuai dengan ketentuan Kampus Merdeka,

dengan durasi program selama 5 bulan. Dalam periode ini, mahasiswa telah

mendapatkan materi tentang Hardware Engineering dan kesempatan untuk

terlibat dalam proyek sesuai bidang dan kemampuan mereka. Untuk

meningkatkan efektivitas pelaksanaan, mungkin diperlukan seleksi tambahan

untuk memastikan partisipasi aktif dari mahasiswa. Hal ini dapat membantu

mengurangi jumlah mahasiswa yang tidak aktif dalam program. Selain itu,

pemilihan peserta yang memiliki latar belakang atau minat yang sesuai dengan

program sangat penting untuk menghindari ketimpangan antar mahasiswa.

Dengan memilih peserta yang selaras dengan tujuan dan materi program,

kolaborasi dalam tim akan menjadi lebih harmonis dan produktif.

### 2. Saran Pelaksanaan Riset

Saat melaksanakan riset dan pengerjaan tugas akhir, terdapat beberapa

saran agar pengerjaannya menjadi maksimal dan sesuai dengan tujuan: Untuk

memulai, sangat penting untuk mendefinisikan dengan jelas tujuan akhir dari

riset yang akan dilakukan. Ini membantu untuk fokus pada hal yang benar-

benar relevan dan realistis untuk dicapai. Selanjutnya, buatlah rencana kerja

yang terinci. Rencana ini harus mencakup jadwal yang disesuaikan dengan

kebutuhan dan prioritas, serta mengidentifikasi milestone atau titik pencapaian

penting selama proses riset. Pilihlah metode riset yang paling sesuai untuk

pertanyaan riset yang diajukan. Pastikan bahwa metode ini tidak hanya cocok

untuk pertanyaan tersebut, tetapi juga mempertimbangkan sumber daya yang

tersedia. Pastikan alat dan sumber daya yang dibutuhkan tersedia dan dapat

diakses sebelum memulai riset. Uji alat-alat ini untuk memastikan

kehandalannya sebelum digunakan dalam riset. Bentuklah tim yang solid

dengan anggota yang memiliki keterampilan dan pengetahuan yang sesuai.

Tetapkan peran dan tanggung jawab dengan jelas untuk masing-masing

anggota tim. Jadwalkan pertemuan rutin untuk memantau kemajuan dan

55

mengatasi masalah yang mungkin muncul selama riset. Gunakan alat

komunikasi yang efektif untuk memfasilitasi kolaborasi di antara anggota tim.

Identifikasi potensi risiko dan siapkan rencana pengelolaan risiko untuk

mengatasi hambatan yang mungkin muncul selama proses riset. Lakukan

analisis data secara sistematis dan hati-hati. Pastikan bahwa metode analisis

yang dipilih sesuai dengan pertanyaan riset yang diajukan. Tulis laporan riset

secara sistematis dan jelas. Persiapkan presentasi yang informatif dan menarik

untuk hasil riset. Terakhir, evaluasi proses riset setelah selesai untuk

memahami pelajaran yang bisa dipetik. Gunakan hasil evaluasi ini untuk

meningkatkan perencanaan dan pelaksanaan riset di masa depan.

BAB VII

REFERENSI

[1] Arisandy, I., & Munawar, A. (2021). Rancang Bangun Alat Suction Pump

berbasis Arduino. Jurnal RESISTOR, 4(3).

[2] Baehaqi, N. (2018). Mengenal Lebih Detail Mengenai Alat Kesehatan

Suction Pump. PT Glorya Medica Abadi, Banyumas.

[3] Djawas, F. U., dkk. (2020). Automatic Suction Pump Continous dilengkapi

Safety berbasis Mikrokontroler. Jurnal Mutiara Elektromedik, 6(2).

[4] Saleh. (2017). Perawatan Peralatan Bedah dan Anestesi (Suction Pump).

Akademi Teknik Elektromedik (ATEM), Muhammadiyah Makassar.

[5] Tian, F., Zhu, D., Shen, X., Li, S., & Xia, L. (2022). Suction detection and

suction suppression of centrifugal blood pump based on the FFT-GAPSO-

LSTM model and speed modulation. Journal of Mechanical Science and

Technology, 36(2).

[6] Cheng, X., Zhang, Y., Wang, H., & Li, J. (2019). Design and Control of a

Suction Pump System for Medical Applications. IEEE Transactions on

Biomedical Engineering, 66(4), 1081-1089.

[7] Park, J., Lee, H., & Kim, S. (2020). Development of a Portable Suction

Pump for Emergency Medical Services. Journal of Medical Devices,

14(2), 025001.

[8] Huang, R., & Chen, Q. (2018). Performance Analysis of a High-Efficiency

Suction Pump for Surgical Applications. Journal of Medical Engineering

& Technology, 42(6), 445-452.

[9] Wang, T., Liu, S., & Yang, Z. (2021). Optimization of Suction Pump

Design Using Computational Fluid Dynamics. Journal of Fluid

Engineering, 143(7), 071204.

[10] Kim, J., & Park, K. (2021). Adaptive Control of a Suction Pump System

Using Machine Learning Techniques. International Journal of Control,

Automation and Systems, 19(4), 1234-1243.

57

LAMPIRAN

- File RAB :

https://drive.google.com/drive/folders/1L2XkwBi1XQ8UEK5-x2-olE9XzXcv5ARe?usp=sharing (https://drive.google.com/drive/folders/1L2XkwBi1XQ8UEK5-x2-olE9XzXcv5ARe?usp=sharing)

- File Manual Book

https://drive.google.com/drive/folders/1bWbrZdA06nWRWtKsF0CBU_jmUkIFKprI?usp=drive_link (https://drive.google.com/drive/folders/1bWbrZdA06nWRWtKsF0CBU_jmUkIFKprI?usp=drive_link)

- File PPT UAS

https://drive.google.com/drive/folders/1C1D8_MIzmTQ1gsLpyK-VniHmHugBfGjH?usp=sharing (https://drive.google.com/drive/folders/1C1D8_MIzmTQ1gsLpyK-VniHmHugBfGjH?usp=sharing)

- File Laporan Akhir

https://drive.google.com/drive/folders/1frmnLo1Kzot4sRw0pGo4kw1pAMz6yqqC?usp=sharing (https://drive.google.com/drive/folders/1frmnLo1Kzot4sRw0pGo4kw1pAMz6yqqC?usp=sharing)

- File Simulasi

https://drive.google.com/drive/folders/16z7-hmSQ-pdtZt8PUJQvqWr2f2PUVGUV?usp=sharing (https://drive.google.com/drive/folders/16z7-hmSQ-pdtZt8PUJQvqWr2f2PUVGUV?usp=sharing)

- File Design Manufaktur

https://drive.google.com/drive/folders/1TpeVMKQU6psYdbnNjupxAK60lBNsooiN?usp=drive_link (https://drive.google.com/drive/folders/1TpeVMKQU6psYdbnNjupxAK60lBNsooiN?usp=drive_link)

- File Project Management

https://drive.google.com/drive/folders/185XtZvp1BYDlhdti7NL6DrhdXYo3HlWb?usp=sharing (https://drive.google.com/drive/folders/185XtZvp1BYDlhdti7NL6DrhdXYo3HlWb?usp=sharing)

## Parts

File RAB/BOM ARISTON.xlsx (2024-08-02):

 | Suction Pump
 | When Technology Meet Manufacture
 | Perum Jalan Sawitsari, Jalan Bunga, No 5-6 Pikgondeng, Condongcatur, Kec. Depok, Kab. Sleman, Daerah Istimewa Yogyakarta
 | CP : Nama | (+62) | email
BILL OF MATERIAL Suction Pump
Suction Pump for Medical Liquid |  |  |  |  |  |  |  |  | Keterangan
Ariston
Purpose detail of Goods / Service | Category | Description of Goods / Service | Spesification | Supplier / Contact Vendor/Link | Unit Budget | Qty | Shipping | Total Budget | Status | Posisi | Note
Electrical
ESP32-S | Component | NodeMCU ESP32 | 5V, 24 pin I/O | https://www.tokopedia.com/cncstorebandung/esp32-s-doit-wifi-bluetooth-iot-dual-core-type-c-38p-plus-kabel-data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 | 74000.00 | 1 | Rp 21000 | Rp 91000 | PO | Belum di Tangan | CNC Store
Motor DC Pump | Component | Taffware DP-538 | 12V 6A, 6L/Min, 0.9 Mpa | https://www.tokopedia.com/bengkel20/taffware-pompa-air-elektrik-diaphragm-pump-12v-72w-130psi-dp538 | 85438.00 | 1 | Rp 25000 | Rp 110438 | PO | Belum di Tangan
Potensiometer Linear | Component | B2Kohm | 2 Kohm, Linear(B) | https://www.tokopedia.com/cncstorebandung/potensio-potensiometer-2k-2kohm-wh148-linier-taper-rotary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 | 1500.00 | 1 | Rp 0 | Rp 1500 | PO | Belum di Tangan | CNC Store
Elco 100nF | Component | DIP IC SMD | 1uF/16 v | https://www.tokopedia.com/itelectro/elco-smd-1uf-16v?extParam=ivf%3Dfalse&src=topads | 750.00 | 2 | Rp 20450 | Rp 21700 | PO | Belum di Tangan | IT Electro
Elco 1000uF | Component | ELCO | 1000 uf 16volt | https://www.tokopedia.com/pcmjakarta/elco-1000uf-1000-uf-16volt-16-volt-16v?extParam=ivf%3Dfalse&src=topads (https://www.tokopedia.com/itelectro/elco-smd-1uf-16v?extParam=ivf%3Dfalse&src=topads) | 195.00 | 2 | Rp 20200 | Rp 20590 | PO | Belum di Tangan | PCM ELEKTRONIK JKT
Saklar kecil | Component | Switch Mini | 2 pin | https://www.tokopedia.com/pcmjakarta/saklar-switch-mini-2-pin-on-off?extParam=src%3Dshop%26whid%3D262513 (https://www.tokopedia.com/itelectro/elco-smd-1uf-16v?extParam=ivf%3Dfalse&src=topads) | 1000.00 | 1 | Rp 0 | Rp 1000 | PO | Belum di Tangan | PCM ELEKTRONIK JKT
kabel jumper | Component | female to male | Panjang 20 cm /40pcs | https://tokopedia.link/dicUfAxLAKb | 15000.00 | 15 | Rp 0 | Rp 15000 | PO | Belum di Tangan | PCM ELEKTRONIK JKT
kabel jumper | Component | female to female | Panjang 20 cm /40pcs | https://tokopedia.link/1dQ0xOHLAKb | 8500.00 | 15 | Rp 0 | Rp 8500 | PO | Belum di Tangan | PCM ELEKTRONIK JKT
kabel jumper | Component | male to male | Panjang 20 cm /40pcs | https://tokopedia.link/YBa4GYPLAKb | 9500.00 | 15 | Rp 0 | Rp 9500 | PO | Belum di Tangan | PCM ELEKTRONIK JKT
IC | Component | Driver motor AG 16 | L298N | https://tokopedia.link/jw4YTM0LAKb (https://www.tokopedia.com/itelectro/elco-smd-1uf-16v?extParam=ivf%3Dfalse&src=topads) | 27200.00 | 1 | Rp 6000 | Rp 34200 | PO | Belum di Tangan | WKH ELEKTRONIK
Dioda | Component | ELCO | In4007 | https://www.tokopedia.com/itelectro/elco-smd-1uf-16v?extParam=ivf%3Dfalse&src=topads | 100.00 | 13 | Rp 0 | Rp 1300 | PO | Belum di Tangan | PCM ELEKTRONIK JKT
Terminal Block | Component | KF350 | Body Dimension: 7.06 (without lock) * 6.77 * 8.69 mm, Pin Diameter : 0.78 mm, Distance Pitch : 3.9 mm | https://www.tokopedia.com/cncstorebandung/cnc-terminal-pcb-block-screw-2-pin-kf301-2p-blue-biru | 500.00 | 8 |  | Rp 2500 | PO | Belum di Tangan | CNC Store
Header | Component | Header female | female 1x16p soket lcd | https://tokopedia.link/KQx72ypMAKb | 1850.00 | 4 | Rp 0 | Rp 7400 | PO | Belum di Tangan | PCM ELEKTRONIK JKT
LED | Component | - | 0.5 watt warna merah | https://tokopedia.link/ZHlpknK4AKb | 1000.00 | 2 | Rp 20200 | Rp 21200 | PO | Belum di Tangan | aNursyam
IC | Component | - | Type 7905 | https://tokopedia.link/gvmBQKS4AKb | 3500.00 | 1 | Rp 0 | Rp 3500 | PO | Belum di Tangan | IT Electro
Resistor | Component | - | tahanan 1k ohm /10 pcs | https://tokopedia.link/BPat6d54AKb | 1000.00 | 2 | Rp 7200 | Rp 8200 | PO | Belum di Tangan | iSee
Resistor | Component | - | tahanan 330 ohm/10pcs | https://tokopedia.link/aqSDBpg5AKb | 700.00 | 2 | Rp 0 | Rp 700 | PO | Belum di Tangan | CNC Store
Kabel Power | Component | - | 220V AC | https://tokopedia.link/9afqi6r5AKb | 15000.00 | 1 | Rp 0 | Rp 15000 | PO | Belum di Tangan | PCM ELEKTRONIK JKT
Sensor Tekanan | Component | presure tranducer transmitter | sensor G1/4/1mpa | https://tokopedia.link/Nif29BF5AKb | 192500.00 | 1 | Rp 14300 | Rp 206800 | PO | Belum di Tangan | Raja Cell Bekasi
Keypad | Component | 4x4 Matrix 16 Key | 8 pin access to 4x4 matrix, Dimensions 6,9x7,6 cm. | https://www.tokopedia.com/cncstorebandung/cnc-4x4-matrix-array-16-key-membrane-membran-switch-keypad | 5000.00 | 1 | Rp 0 | Rp 5000 | PO | Belum di Tangan | CNC Store
LCD Keypad | Component | 20 x 4 | 5V, Size 64.5x16mm | https://www.tokopedia.com/cncstorebandung/lcd-1602-char-green-backlight-with-i2c-serial-interface-module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 | 25500.00 | 1 | Rp 0 | Rp 25500 | PO | Belum di Tangan | CNC Store
Spacer PCB | Component | M3x20mm | Thread Size : M3, Length : 20mm, Material : Brass, Gold Tone | https://www.tokopedia.com/cncstorebandung/cnc-spacer-pcb-metal-spacer-logam-spacer-copper-20mm-x-3mm-3m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 | 1500.00 | 8 | Rp 0 | Rp 15000 | PO | Belum di Tangan | CNC Store
Power Supply | Component | Adaptor DC 12 V 15 A | Input AC 100-240V, Out 12VDC, Jack DC 2,5x5,5mm | https://www.tokopedia.com/cncstorebandung/power-supply-switching-12v-15a-high-quality-adaptor-jaring-180w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 | 105000.00 | 1 | Rp 0 | Rp 105000 | PO | Belum di Tangan | CNC Store
DC Step Down | Component | LM2596 | Input 5-80V, Out 5V-20V. Dimensi 43x21x14 mm | https://www.tokopedia.com/cncstorebandung/xl7015-step-down-dc-dc-adjustable-5v-80v-to-5v-20v-0-8a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 | 10700.00 | 1 | Rp 0 | 10700.00 | PO | Belum di Tangan | CNC Store
Push Button | Component | DS-134 | width: 3MM, thickness: 0.5MM | https://www.tokopedia.com/cncstorebandung/push-button-ds-134-10mm-reset-switch-green-hijau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 | 10700.00 | 1 | Rp 0 | Rp 10700 | PO | Belum di Tangan | CNC Store
 |  |  |  | Mecanical
Biaya pembuatan alat | Jasa |  |  |  | 1500000.00 | 1 | Rp. 1.500.000 | Rp 1500000 | PO | Belum di Tangan

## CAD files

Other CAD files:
Desain/Mekanik/Assembly/Buttom Cover PCB.iam
Desain/Mekanik/Assembly/Lcd i2c.iam
Desain/Mekanik/Assembly/RV24 v6.iam
Desain/Mekanik/Assembly/Suction_Pump_Assembly.iam
Desain/Mekanik/Assembly/Water Pump.iam
Desain/Mekanik/Assembly/boto suction pump.iam
Desain/Mekanik/Drawing/Body v5.idw
Desain/Mekanik/Drawing/Bottom_Cover.idw
Desain/Mekanik/Drawing/Handle.idw
Desain/Mekanik/Drawing/Keypad 4x4.idw
Desain/Mekanik/Drawing/LCD 20x4 I2C.idw
Desain/Mekanik/Drawing/Main_Cover.idw
Desain/Mekanik/Drawing/NIPPLE 2.idw
Desain/Mekanik/Drawing/NIPPLE SUCTION.idw
Desain/Mekanik/Drawing/NIPPLE.idw
Desain/Mekanik/Drawing/PS 011 R1-1.idw
Desain/Mekanik/Drawing/Potentiometer Knob.idw
Desain/Mekanik/Drawing/Section_Pump_Assembly.idw
Desain/Mekanik/Drawing/Switch.idw
Desain/Mekanik/Drawing/Tabung-1.idw
Desain/Mekanik/Part/Cover/Bottom_Cover.ipt
Desain/Mekanik/Part/Cover/Handle_Part.ipt
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

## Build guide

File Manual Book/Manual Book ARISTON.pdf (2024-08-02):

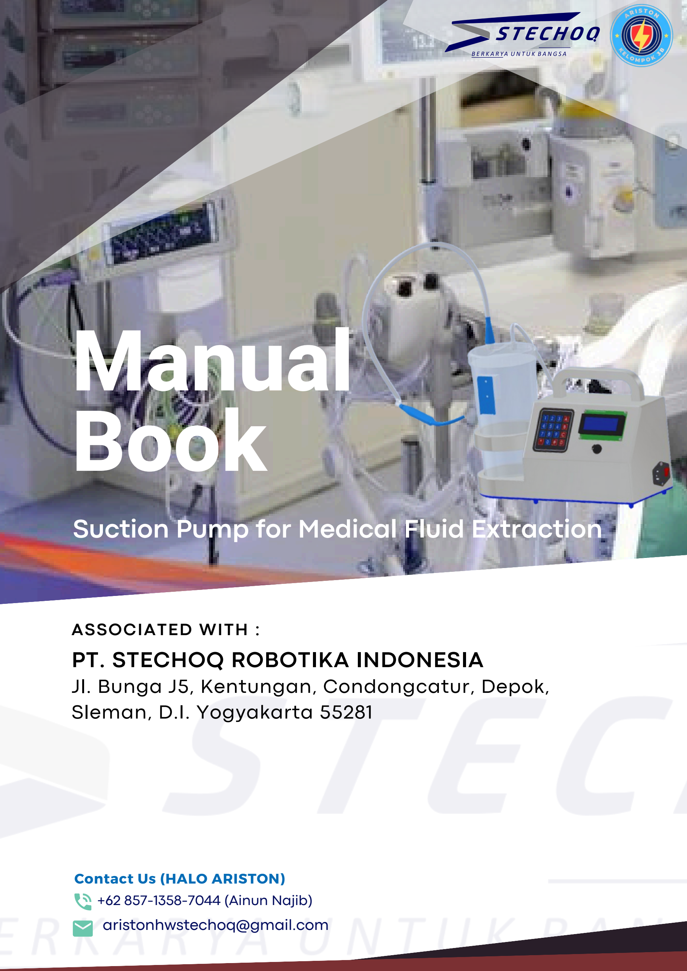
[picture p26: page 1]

# Manual Book

## Suction Pump for Medical Fluid Extraction

### ARISTON TEAM

PT. STECHOQ ROBOTIKA INDONESIA Jl. Bunga J5, Kentungan, Condongcatur, Depok, Sleman, D.I. Yogyakarta 55281

ASSOCIATED WITH :

+62 857-1358-7044 (Ainun Najib)

aristonhwstechoq@gmail.com

Contact Us (HALO ARISTON)

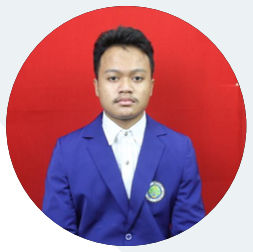
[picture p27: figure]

Sholich Ibnu Damar

3D Design
Universitas Negeri Malang

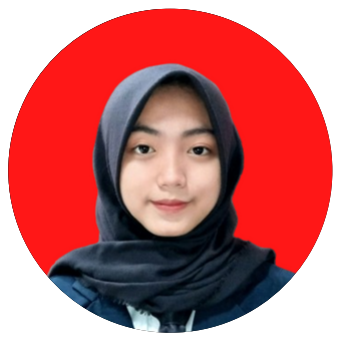
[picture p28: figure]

Tri Rejeki Andani

3D Design
Universitas Negeri Surabaya

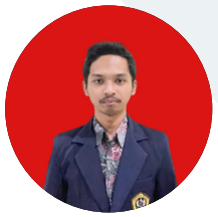
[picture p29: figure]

Sri Aji Eka Mahendra

Electronics Engineer
Universitas Merdeka Malang

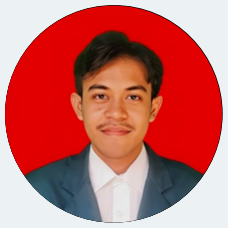
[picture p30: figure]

Ainun Najib Khasbunallah

Project Manager and Electronics Engineer Universitas Diponegoro Semarang

# OUR TEAM

SUCTION PUMP FOR MEDICAL
FLUID EXTRACTION

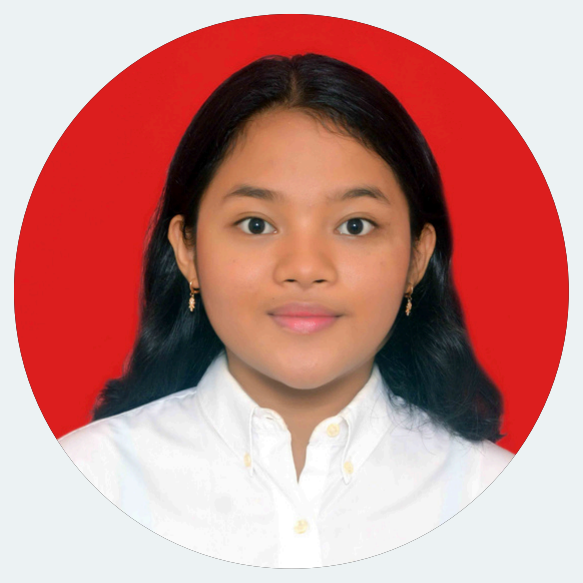
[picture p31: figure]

Aurelia Alika Putri Widiyanta

Administratif and Support Engineer Politeknik Negeri Semarang

# PROFIL PRODUK

Suction Pump for Medical Fluid Extraction adalah perangkat medis yang dirancang khusus untuk mengeluarkan cairan tubuh seperti darah, lendir, dan cairan lainnya dari tubuh pasien atau area operatif secara cepat dan efisien. Alat ini sangat penting dalam berbagai prosedur medis, termasuk pembedahan, perawatan pasien dengan gangguan cairan, dan situasi darurat medis. Suction pump ini menawarkan solusi andal untuk meningkatkan kualitas pelayanan kesehatan. Selain itu, suction pump ini dilengkapi dengan layanan IoT (Internet of Things) yang memungkinkan pemantauan kinerja alat secara real-time yang optimal dan mengurangi downtime.

Suction Pump for Medical Fluid Extraction adalah perangkat medis yang dirancang khusus untuk mengeluarkan cairan tubuh seperti darah, lendir, dan cairan lainnya dari tubuh pasien atau area operatif secara cepat dan efisien. Alat ini sangat penting dalam berbagai prosedur medis, termasuk pembedahan, perawatan pasien dengan gangguan cairan, dan situasi darurat medis. Suction pump ini menawarkan solusi andal untuk meningkatkan kualitas pelayanan kesehatan. Selain itu, suction pump ini dilengkapi dengan layanan IoT (Internet of Things) yang memungkinkan pemantauan kinerja alat secara real-time yang optimal dan mengurangi downtime.

## Suction Pump for Medical Fluid Extraction

# BAGIAN PRODUK

## Suction Pump for Medical Fluid Extraction

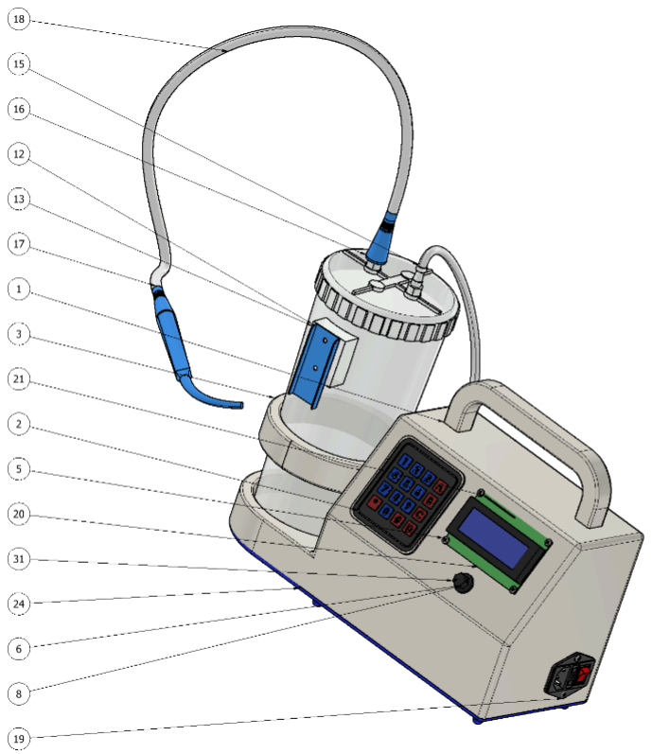
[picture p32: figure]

# KETERANGAN PART :

## Suction Pump for Medical Fluid Extraction

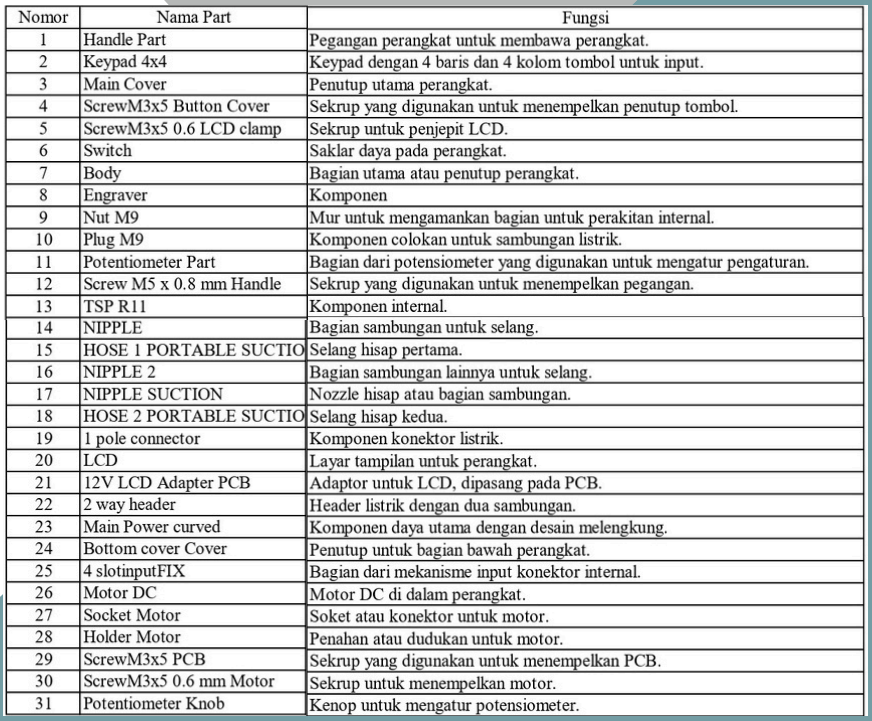
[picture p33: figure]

# SPECIFICATION

## Suction Pump for Medical Fluid Extraction

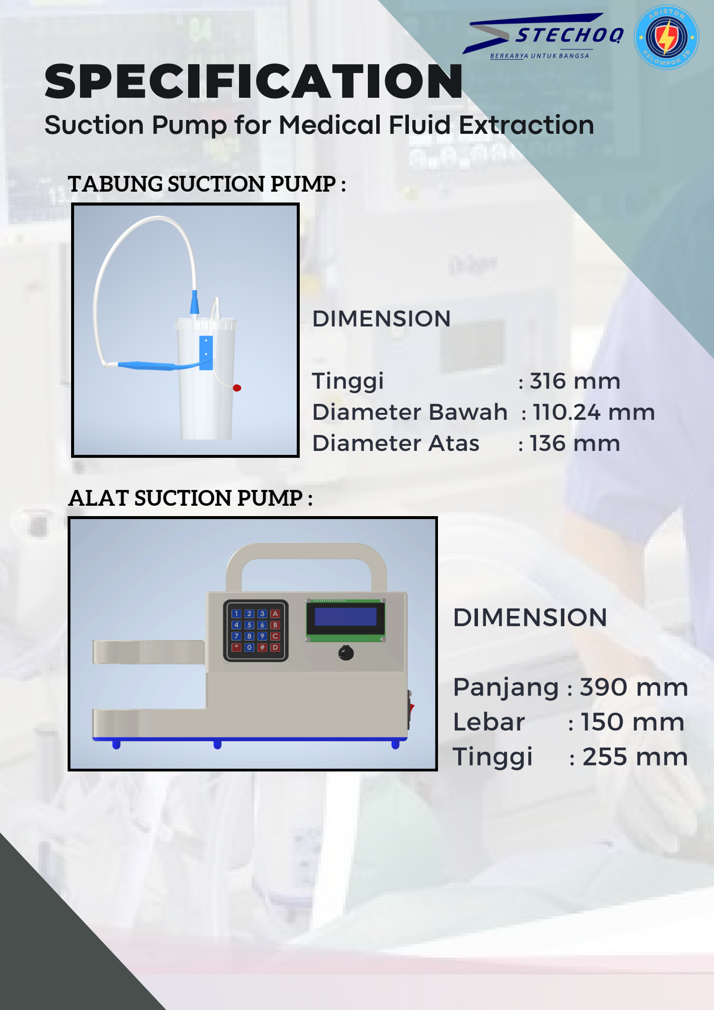
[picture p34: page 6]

## TABUNG SUCTION PUMP :

# DIMENSION

# Panjang : 390 mm

Lebar | : 150 mm
Tinggi | : 255 mm

## DIMENSION

Tinggi | : 316 mm

## Diameter Bawah : 110.24 mm Diameter Atas : 136 mm

## ALAT SUCTION PUMP :

# HOW TO USE ?

1.Mulai:
Nyalakan alat untuk memulai proses.

### 2. Periksa Status Alat:

Alat memeriksa kesiapan komponen. Jika tidak siap, periksa dan perbaiki masalah.

### 3. Aktifkan Wi-Fi:

Alat mencoba menghubungkan ke jaringan Wi-Fi.

### 4. Periksa Koneksi Wi-Fi:

Jika koneksi gagal, periksa jaringan Wi-Fi dan coba lagi.

### 5. Pilih Mode Kontrol:

Pilih antara kontrol manual atau kontrol melalui IoT.

### 6. Kontrol Manual:

Masukkan kecepatan motor melalui keypad.
Tekan tombol konfirmasi untuk memulai motor.

### 7. Kontrol IoT:

Atur kecepatan motor melalui aplikasi IoT menggunakan slider.
Nilai kecepatan dikirim ke alat untuk memulai motor.

### 8. Pengisapan Cairan:

Motor menggerakkan mekanisme hisap dan cairan terisi ke dalam tabung.

### 9. Tampilkan Hasil:

Hasil pengisian cairan ditampilkan pada LCD alat.
Dalam mode IoT, hasil juga dikirim ke Cloud.

### 10. Selesai:

Proses selesai dan alat dapat dimatikan atau digunakan kembali.

## Suction Pump for Medical Fluid Extraction

## LANGKAH KERJA ALAT SUCTION PUMP :

# HOW TO MAINTENANCE ?

Cara Merawat Suction Pump for Medical Fluid Extraction
1.Pembersihan Rutin:
Bersihkan semua bagian yang terkontaminasi dengan cairan tubuh setelah setiap penggunaan.
Gunakan desinfektan medis yang sesuai untuk membersihkan bagian dalam dan luar alat.
Bilas dan keringkan semua komponen sebelum menyimpannya. 2.Pemeriksaan Visual:
Periksa kondisi selang dan tabung untuk memastikan tidak ada kebocoran atau kerusakan.
Pastikan semua sambungan dan konektor terpasang dengan benar dan tidak longgar.
Periksa filter dan ganti jika terlihat kotor atau tersumbat.
3.Perawatan Motor dan Mekanikal:
Lakukan pengecekan berkala pada motor dan bagian mekanikal untuk memastikan tidak ada suara aneh atau getaran yang tidak normal. Lumasi bagian-bagian yang bergerak sesuai dengan panduan pabrikan. 4.Pemeriksaan Listrik:
Pastikan semua kabel listrik dalam kondisi baik dan tidak ada kerusakan pada isolasi.
Periksa koneksi listrik untuk memastikan tidak ada masalah pada plug atau socket.
5.Penyimpanan yang Tepat:
Simpan alat di tempat yang bersih, kering, dan jauh dari sinar matahari langsung.
Pastikan alat disimpan dalam kondisi yang tidak memungkinkan kontaminasi atau kerusakan.

### Suction Pump for Medical Fluid Extraction

# HOW TO CALIBRATION?

Cara Kalibrasi Suction Pump for Medical Fluid Extraction
1.Persiapan Alat dan Kalibrator:
Pastikan alat dalam kondisi bersih dan siap untuk dikalibrasi. Siapkan perangkat kalibrator yang sesuai, biasanya berupa alat pengukur tekanan atau alat khusus untuk kalibrasi suction pump. 2.Kalibrasi Tekanan:
Hubungkan alat kalibrator ke suction pump sesuai dengan instruksi pabrikan.
Nyalakan suction pump dan atur kecepatan atau tingkat hisap yang akan dikalibrasi.
Bandingkan tekanan yang ditunjukkan oleh suction pump dengan pembacaan pada kalibrator.
Jika ada perbedaan, sesuaikan pengaturan alat hingga tekanan yang ditunjukkan oleh suction pump sesuai dengan kalibrator. 3.Verifikasi Aliran:
Hubungkan alat ke sistem pengukur aliran jika tersedia.
Pastikan aliran cairan sesuai dengan spesifikasi pabrikan.
Sesuaikan pengaturan jika diperlukan untuk memastikan aliran sesuai dengan standar yang ditetapkan.
4.Pengujian Kinerja:
Setelah kalibrasi tekanan dan aliran, lakukan pengujian kinerja alat dengan menggunakan cairan simulasi.
Periksa apakah alat berfungsi dengan baik dan mengeluarkan cairan sesuai dengan pengaturan.
5.Dokumentasi dan Pelabelan:
Catat hasil kalibrasi dalam log perawatan alat.
Beri label pada alat dengan tanggal dan hasil kalibrasi serta tanda tangan teknisi yang melakukan kalibrasi.
6.Frekuensi Kalibrasi:
Lakukan kalibrasi secara berkala sesuai dengan panduan pabrikan, biasanya setiap 6 bulan atau setelah perbaikan besar.
Kalibrasi juga harus dilakukan setelah penggantian komponen utama atau setelah alat digunakan dalam kondisi yang ekstrem.

### Suction Pump for Medical Fluid Extraction

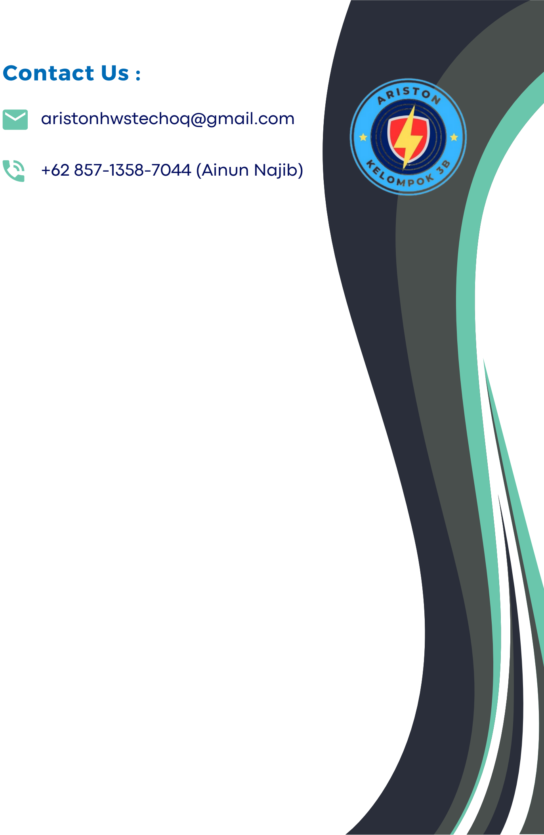
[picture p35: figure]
+62 857-1358-7044 (Ainun Najib); aristonhwstechoq@gmail.com; Contact Us :

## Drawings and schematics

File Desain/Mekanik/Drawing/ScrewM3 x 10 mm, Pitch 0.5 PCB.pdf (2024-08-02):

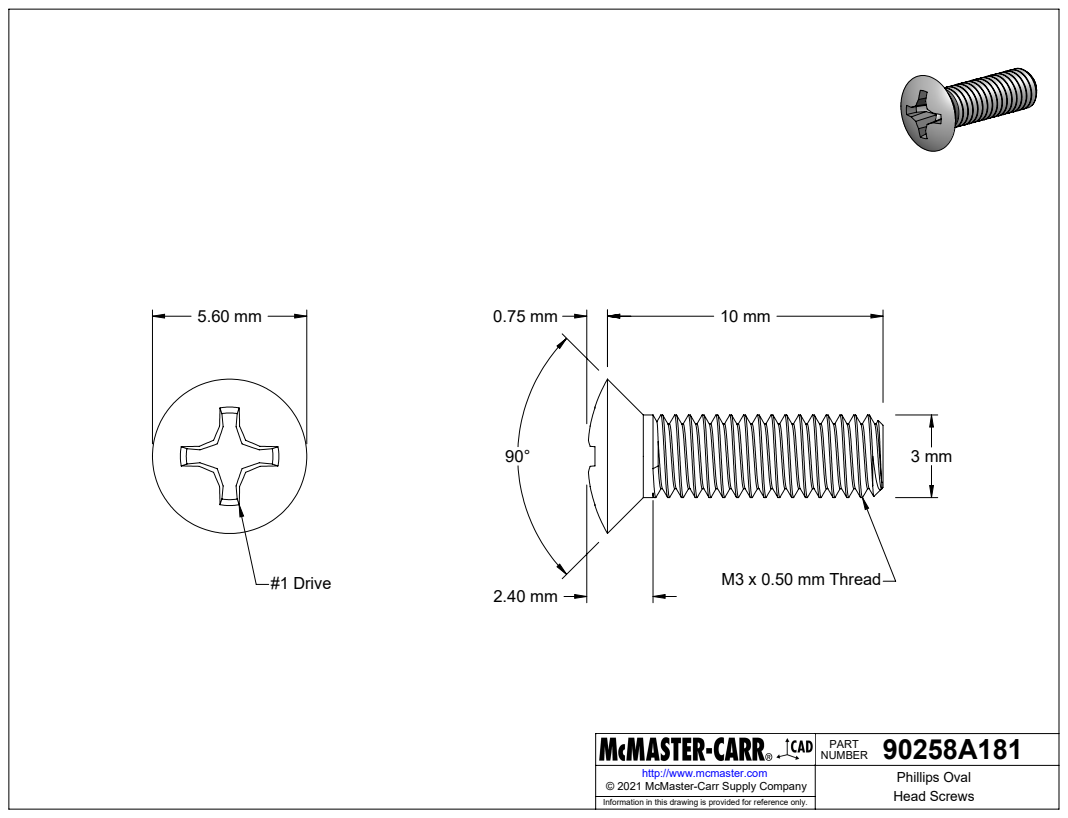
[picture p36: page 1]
M3 x 0.50 mm Thread; #1 Drive

90258A181 PART NUMBER

http://www.mcmaster.com | Phillips Oval Head Screws © 2021 McMaster-Carr Supply Company

Information in this drawing is provided for reference only.

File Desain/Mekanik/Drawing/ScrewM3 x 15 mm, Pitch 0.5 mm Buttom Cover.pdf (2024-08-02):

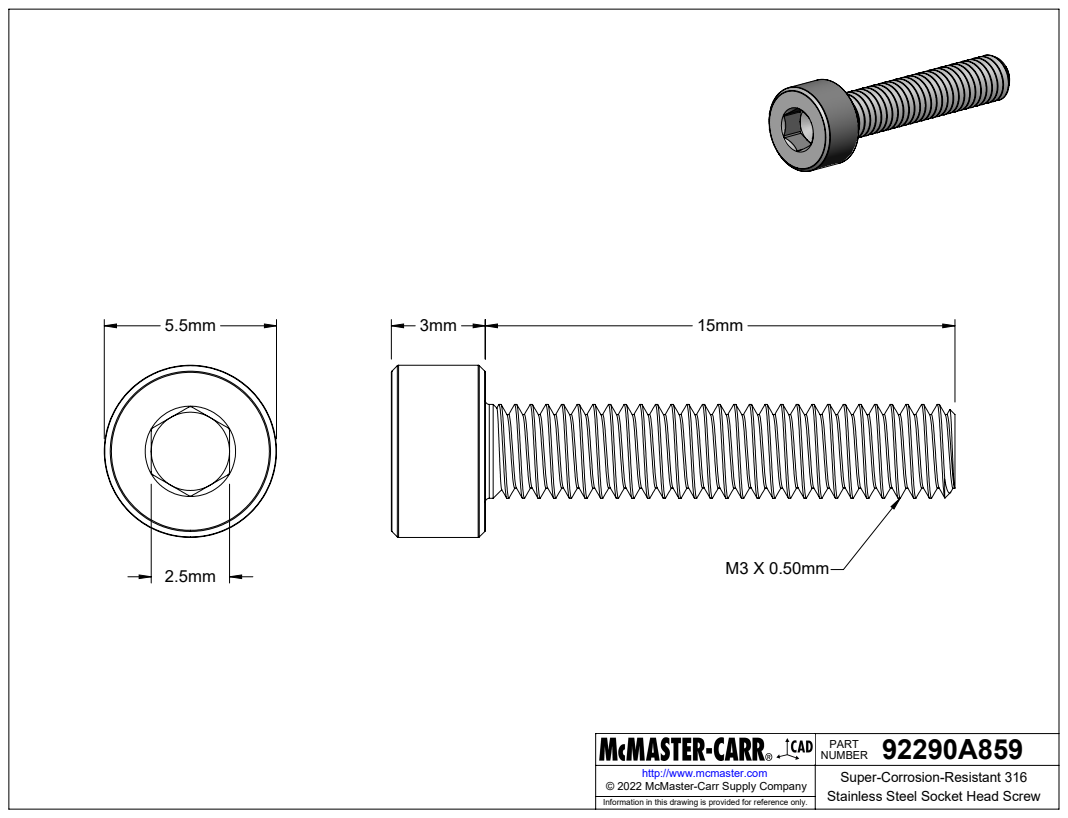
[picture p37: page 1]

92290A859 PART NUMBER

http://www.mcmaster.com | Super-Corrosion-Resistant 316 Stainless Steel Socket Head Screw © 2022 McMaster-Carr Supply Company

Information in this drawing is provided for reference only.

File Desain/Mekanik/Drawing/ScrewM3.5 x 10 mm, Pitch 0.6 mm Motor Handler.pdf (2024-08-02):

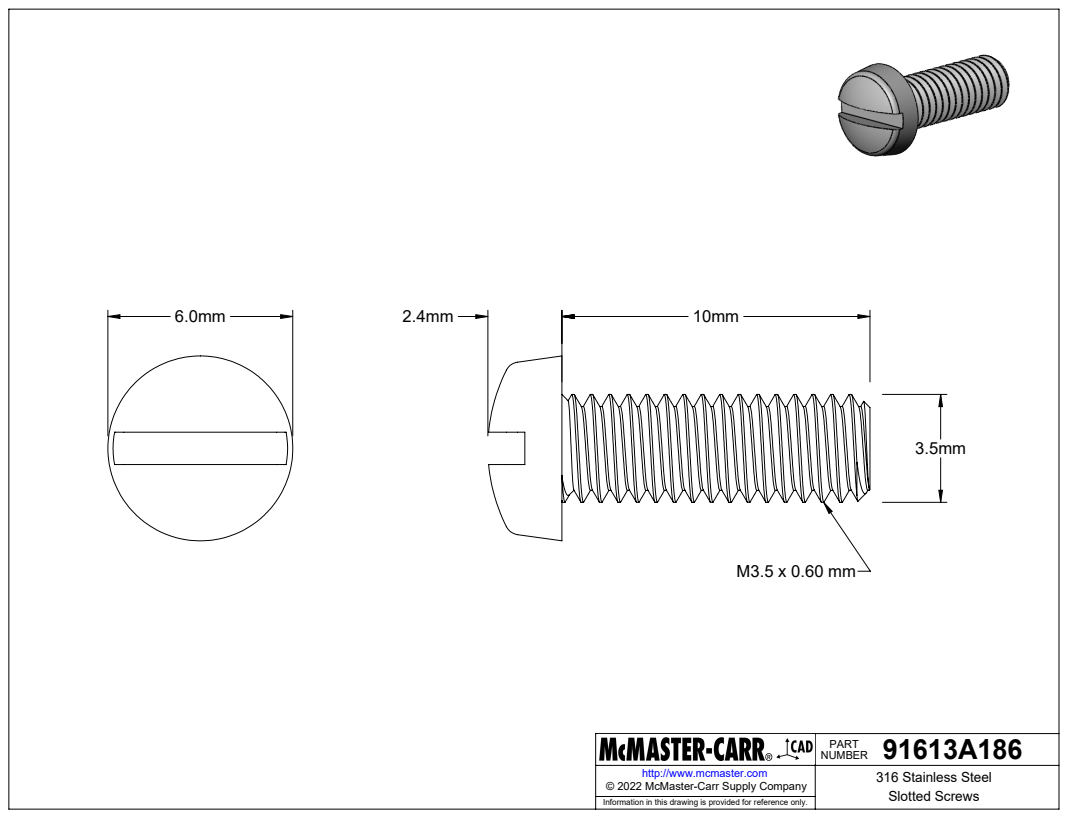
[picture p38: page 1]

91613A186 PART NUMBER

http://www.mcmaster.com | 316 Stainless Steel Slotted Screws © 2022 McMaster-Carr Supply Company

Information in this drawing is provided for reference only.

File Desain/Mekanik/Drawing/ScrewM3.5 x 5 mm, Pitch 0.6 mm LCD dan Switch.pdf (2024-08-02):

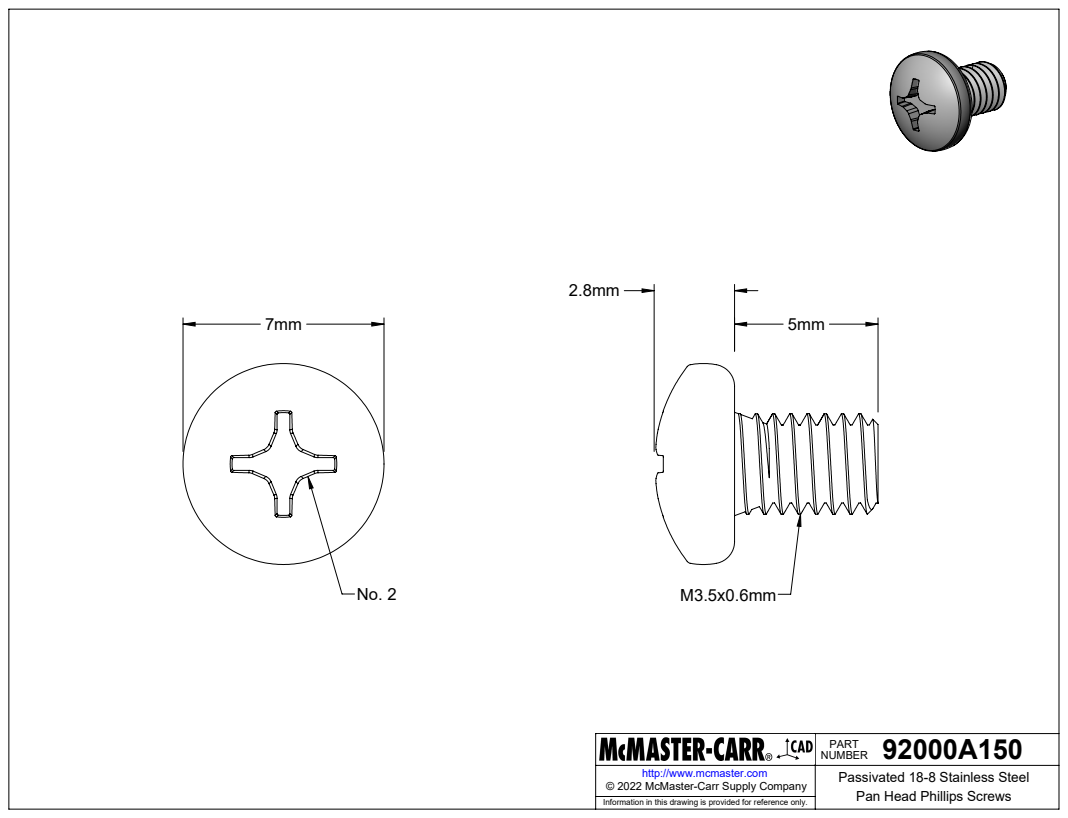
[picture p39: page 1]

92000A150 PART NUMBER

http://www.mcmaster.com | Passivated 18-8 Stainless Steel Pan Head Phillips Screws © 2022 McMaster-Carr Supply Company

Information in this drawing is provided for reference only.

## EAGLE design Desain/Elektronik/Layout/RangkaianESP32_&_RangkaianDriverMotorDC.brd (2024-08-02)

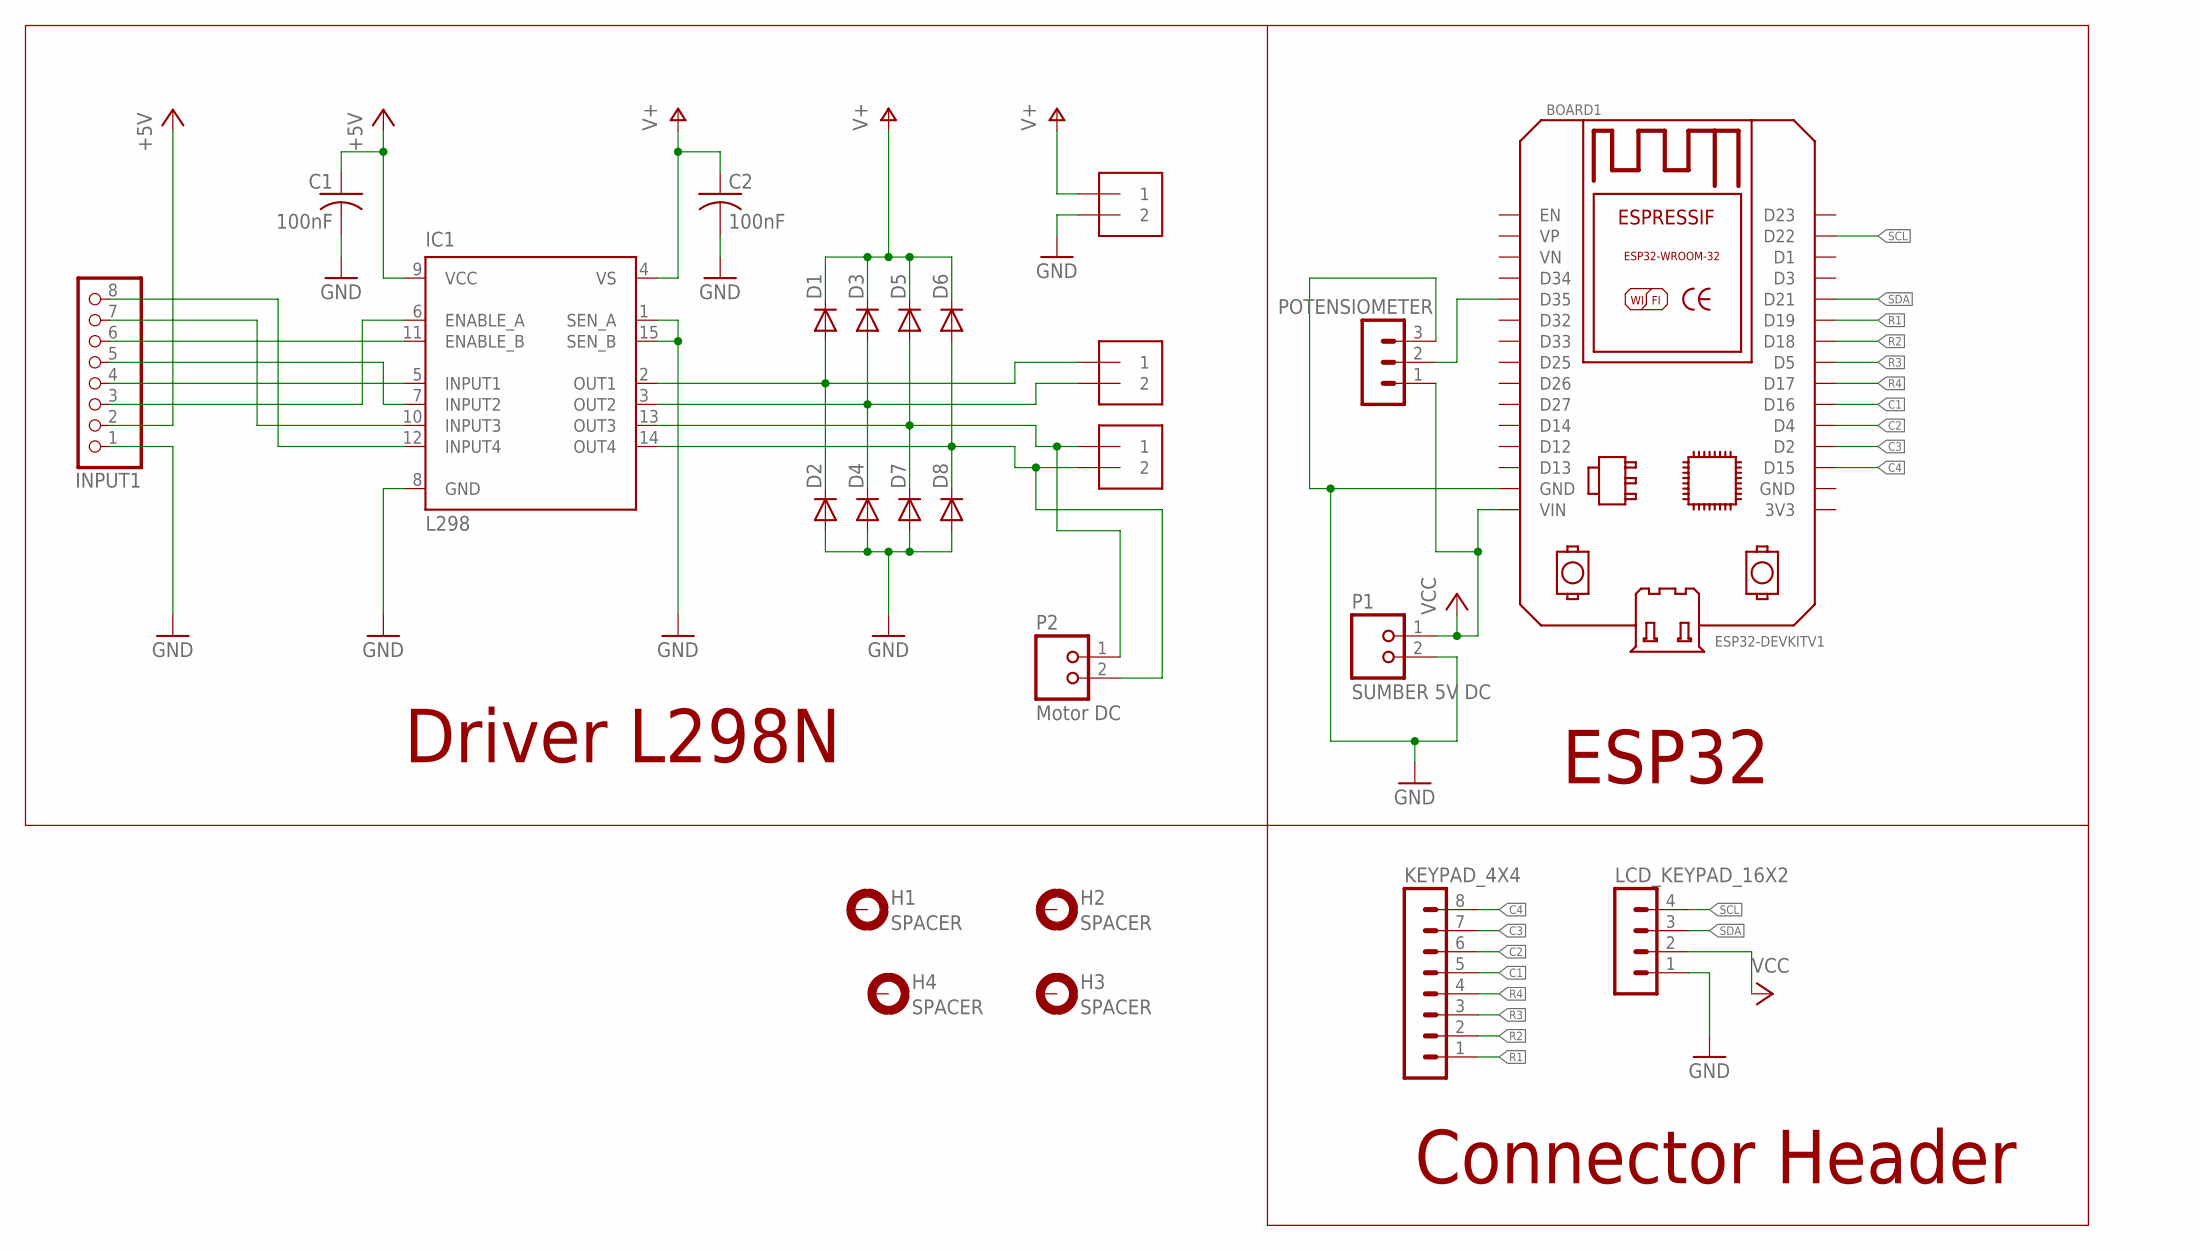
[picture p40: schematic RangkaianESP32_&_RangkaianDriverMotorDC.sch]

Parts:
BOARD1: ESP32DEVKITV1SHRIDATTDUDHAT; ESP32-DEVKITV1
C1, C2: 100nF; C050-024X044
D1, D2, D3, D4, D5, D6, D7, D8: DIODE-D-5; D-5
H1, H2, H3, H4: SPACER; 3,0-PAD
IC1: L298; MULTIWATT-15
INPUT1: PINHD-1X8; 1X08
KEYPAD_4X4: MA08-1
LCD_KEYPAD_16X2: MA04-1
OUTPUT1, OUTPUT2, OUTPUT3: 1X2-3.5MM
P1: SUMBER 5V DC; TERMINAL_2P
P2: Motor DC; TERMINAL_2P
POTENSIOMETER: MA03-1

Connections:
+5V: C1.1, IC1.9 (VCC), INPUT1.2
C1: BOARD1.D16, KEYPAD_4X4.5
C2: BOARD1.D4, KEYPAD_4X4.6
C3: BOARD1.D2, KEYPAD_4X4.7
C4: BOARD1.D15, KEYPAD_4X4.8
GND: BOARD1.GND, C1.2, C2.2, D2.A, D4.A, D7.A, D8.A, IC1.1 (SEN_A), IC1.8 (GND), IC1.15 (SEN_B), INPUT1.1, LCD_KEYPAD_16X2.1, OUTPUT1.2, P1.2, POTENSIOMETER.3
unnamed: D1.A, D2.C, IC1.2 (OUT1), OUTPUT2.1
unnamed: D3.A, D4.C, IC1.3 (OUT2), OUTPUT2.2
unnamed: D6.A, D8.C, IC1.14 (OUT4), OUTPUT3.2, P2.2
unnamed: D5.A, D7.C, IC1.13 (OUT3), OUTPUT3.1, P2.1
unnamed: IC1.5 (INPUT1), INPUT1.4
unnamed: IC1.7 (INPUT2), INPUT1.5
unnamed: IC1.6 (ENABLE_A), INPUT1.3
unnamed: IC1.11 (ENABLE_B), INPUT1.6
unnamed: IC1.10 (INPUT3), INPUT1.7
unnamed: IC1.12 (INPUT4), INPUT1.8
unnamed: BOARD1.D35, POTENSIOMETER.2
R1: BOARD1.D19, KEYPAD_4X4.1
R2: BOARD1.D18, KEYPAD_4X4.2
R3: BOARD1.D5, KEYPAD_4X4.3
R4: BOARD1.D17, KEYPAD_4X4.4
SCL: BOARD1.D22, LCD_KEYPAD_16X2.4
SDA: BOARD1.D21, LCD_KEYPAD_16X2.3
V+: C2.1, D1.C, D3.C, D5.C, D6.C, IC1.4 (VS), OUTPUT1.1
VCC: BOARD1.VIN, LCD_KEYPAD_16X2.2, P1.1, POTENSIOMETER.1

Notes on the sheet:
Driver L298N
ESP32
Connector Header

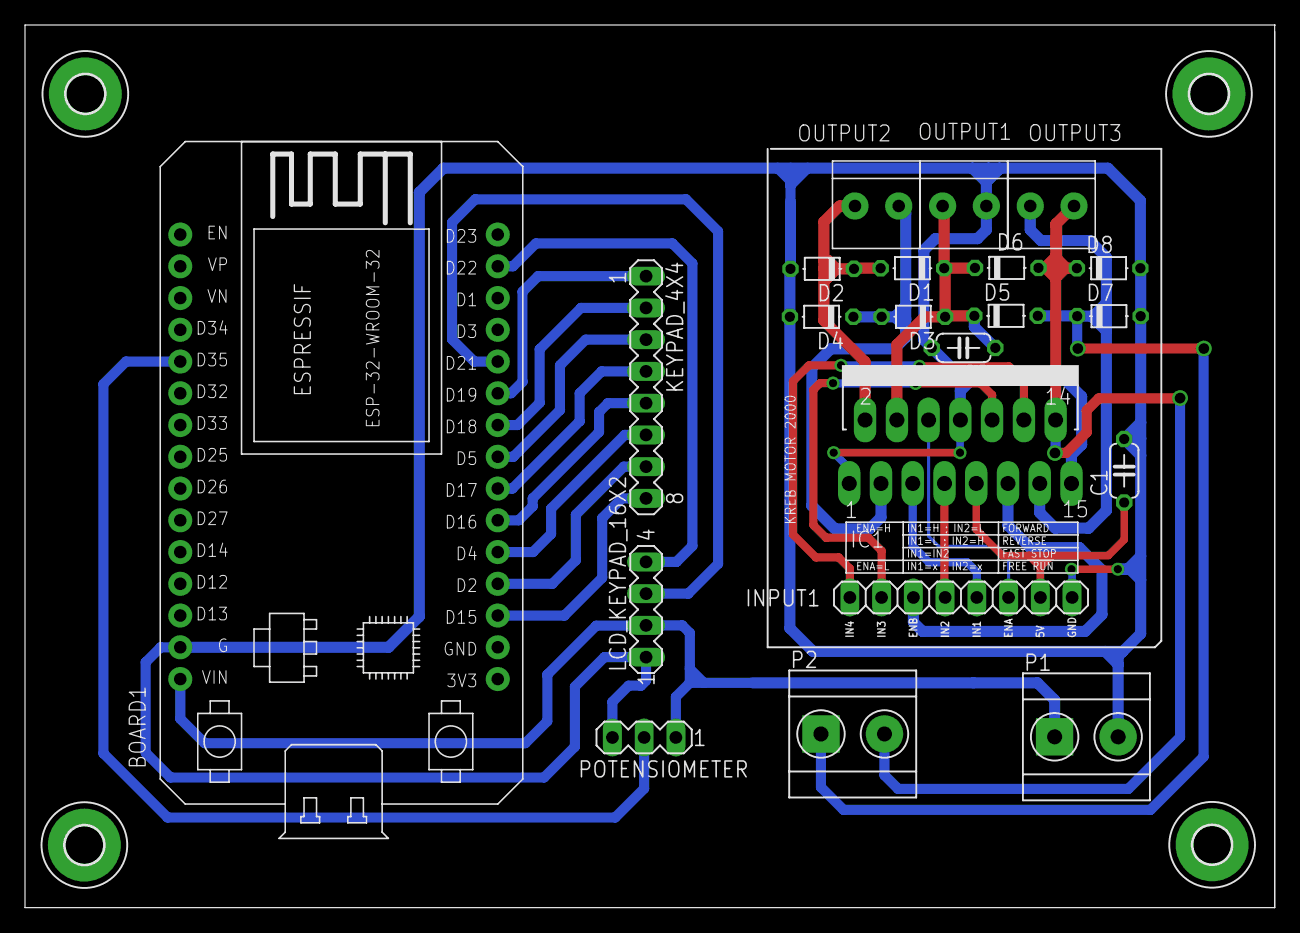
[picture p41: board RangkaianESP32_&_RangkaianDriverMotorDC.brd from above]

Board: 2 copper layers, 100.0 x 70.6 mm, 25 parts (0 on the bottom side), 25 nets.

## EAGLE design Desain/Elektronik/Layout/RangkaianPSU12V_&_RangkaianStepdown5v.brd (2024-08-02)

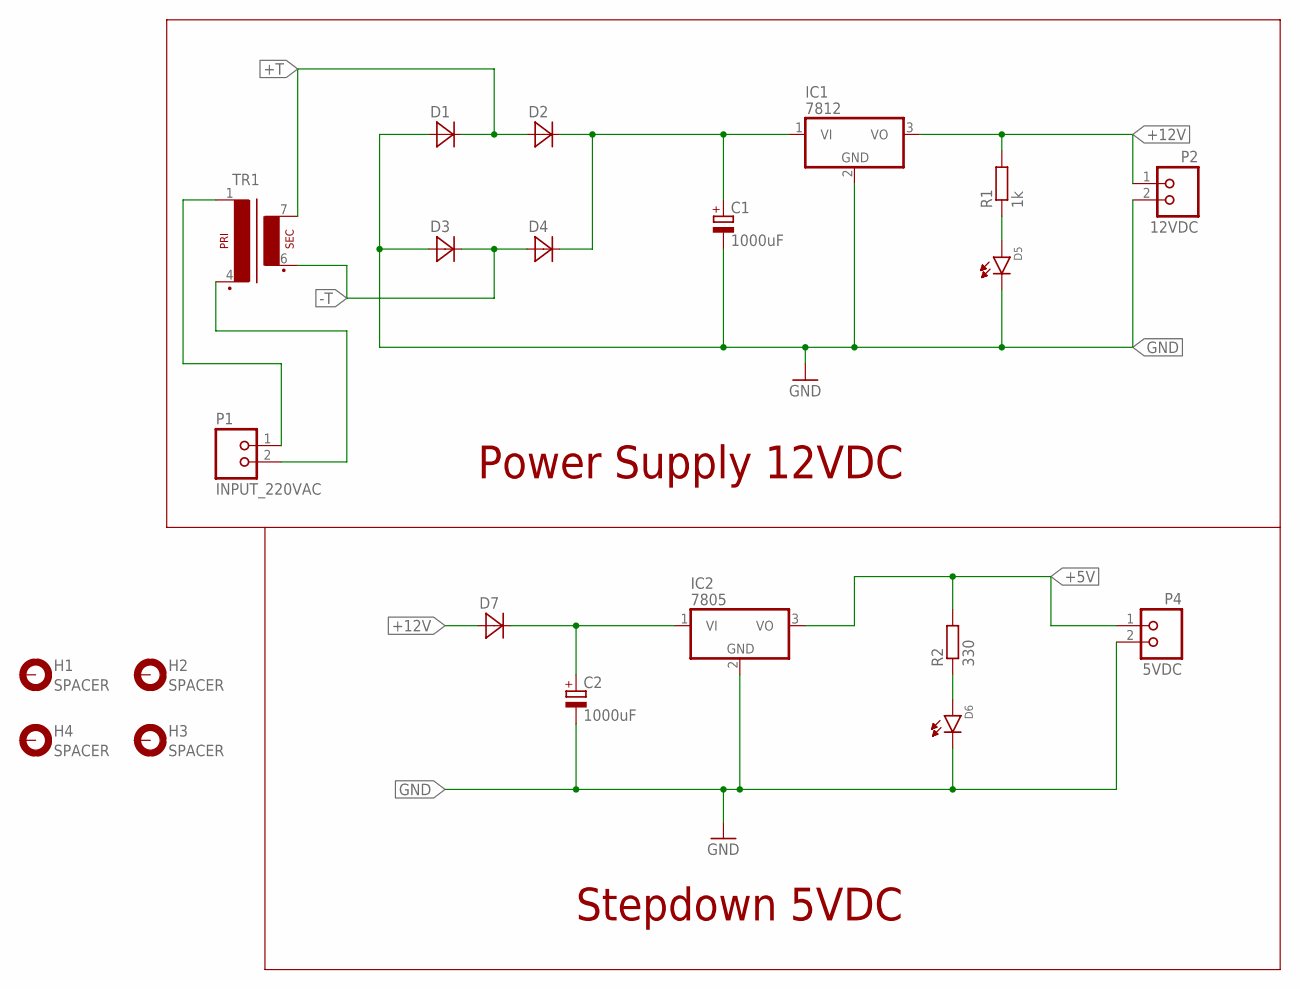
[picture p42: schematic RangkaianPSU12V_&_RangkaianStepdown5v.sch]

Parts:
C1, C2: 1000uF; E5-4
D1, D2, D3, D4, D7: 1N4148; DO35-10
D5, D6: LED-3MM; LED
H1, H2, H3, H4: SPACER; 3,0-PAD
IC1: 7812; TO220V
IC2: 7805; TO220V
P1: INPUT_220VAC; TERMINAL_2P
P2: 12VDC; TERMINAL_2P
P4: 5VDC; TERMINAL_2P
R1: 1k; AXIAL
R2: 330; AXIAL
TR1: EE20-1

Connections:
+5V: IC2.3 (VO), P4.1, R2.2
+12V: D7.A, IC1.3 (VO), P2.1, R1.2
+T: D1.K, D2.A, TR1.7 (S4)
-T: D3.K, D4.A, TR1.6 (S3)
GND: C1.-, C2.-, D1.A, D3.A, D5.2, D6.2, IC1.2 (GND), IC2.2 (GND), P2.2, P4.2
unnamed: P1.1, TR1.1
unnamed: P1.2, TR1.4 (P2)
unnamed: C1.+, D2.K, D4.K, IC1.1 (VI)
unnamed: D5.1, R1.1
unnamed: C2.+, D7.K, IC2.1 (VI)
unnamed: D6.1, R2.1

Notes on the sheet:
Power Supply 12VDC
Stepdown 5VDC

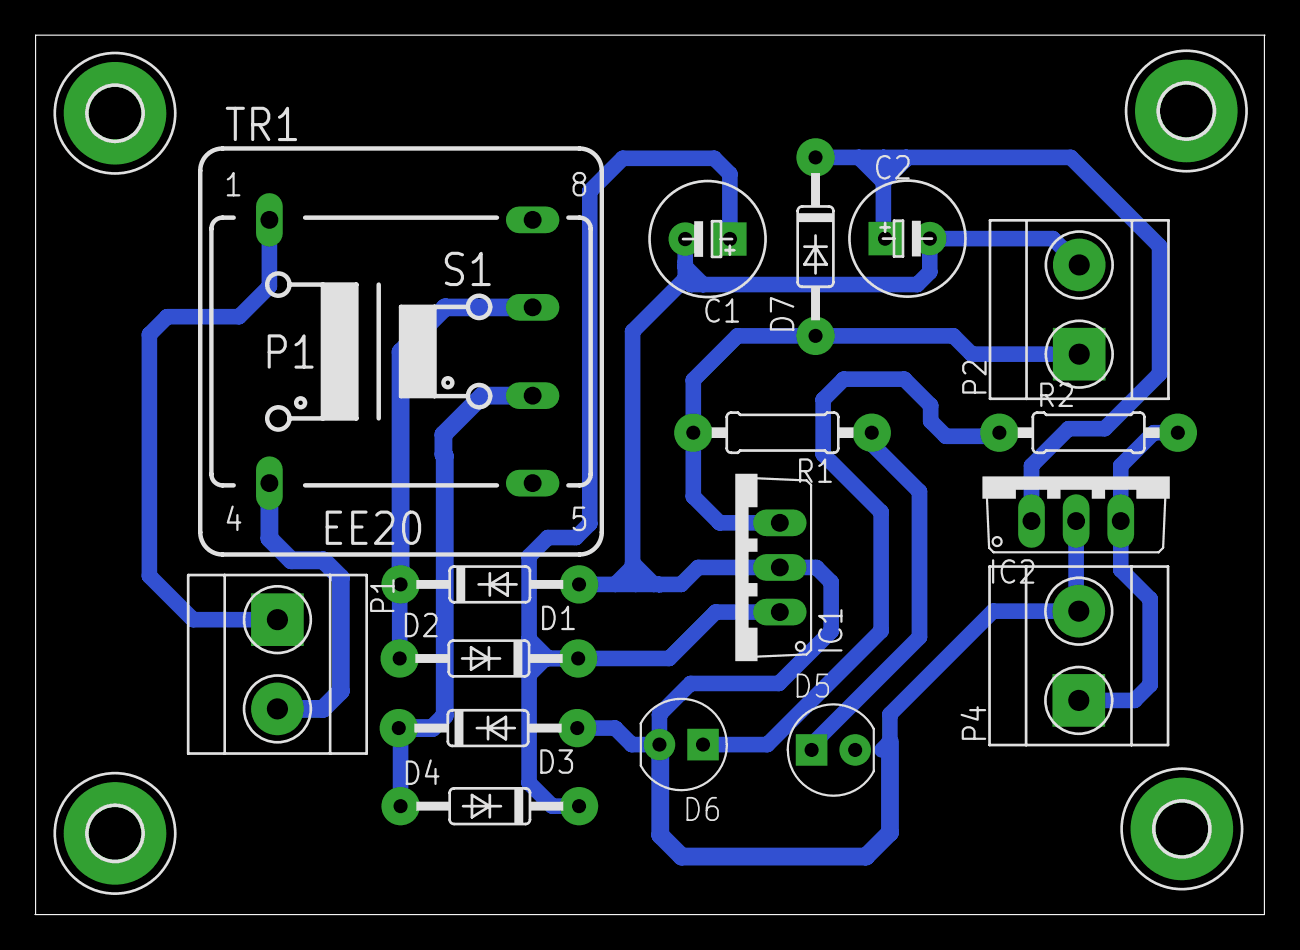
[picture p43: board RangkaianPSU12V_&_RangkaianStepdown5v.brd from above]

Board: 2 copper layers, 70.0 x 50.1 mm, 21 parts (0 on the bottom side), 11 nets.
